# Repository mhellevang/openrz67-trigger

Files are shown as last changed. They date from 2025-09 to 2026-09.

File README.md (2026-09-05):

# openrz67-trigger

ESP32 firmware for remote-triggering the Mamiya RZ67 analog camera over Bluetooth LE. It runs on an ESP32-C3 connected to the camera's electrical remote port and is controlled from the companion Android app, [openrz67-android](https://github.com/openrz67/openrz67-android).

## Features

* Instant shutter release
* Bulb mode for remote long exposures
* Self-timer countdown with app-configurable duration
* Power-optimized: 80 MHz CPU with light sleep and 0 dBm BLE TX power, running off a small LiPo

## Hardware

The current prototype is a custom PCB (design and fabrication files in [`pcb/`](pcb/)):

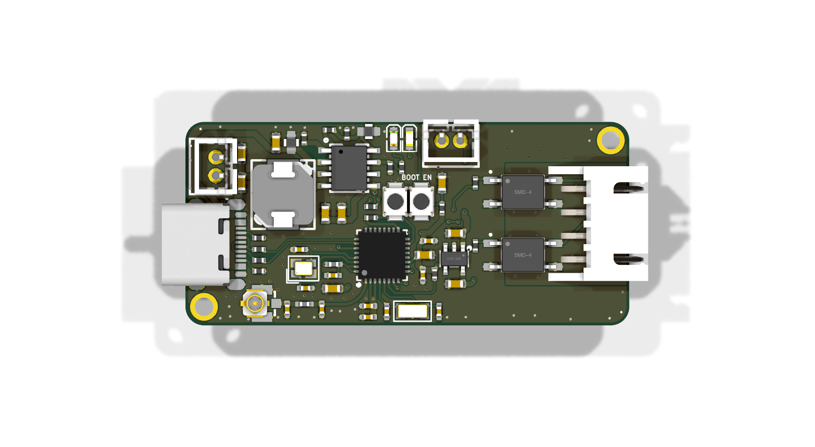
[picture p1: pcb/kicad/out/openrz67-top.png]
Custom PCB


The PCB source is the KiCad project in [`pcb/kicad/`](pcb/kicad/) (ported from EasyEDA Pro in September 2026). Generated Gerber/BOM/position files are in `pcb/kicad/out/`. The fabricated 2025-09-23 revision and the EasyEDA Pro exports are kept under [`pcb/archive/`](pcb/archive/).

The current source is **rev 2, not yet fabricated**: it swaps the G6K relays for PhotoMOS parts and changes `U4` to a side-entry connector; the battery connector stays on top. The board pictured above is rev 2, and the enclosure in [`case/`](case/) is drawn for it (not yet print-tested). Connector part numbers and geometry are documented in [`pcb/kicad/README.md`](pcb/kicad/README.md), which is the authoritative source for them.

* 1× ESP32-C3FH4
* 2× Toshiba TLP172AM PhotoMOS relays (solid-state, isolated) to close the shutter contacts
* Supporting components per the [BOM](pcb/kicad/out/openrz67-bom.csv)
* 2.4 GHz antenna with U.FL connector
* 250 mAh LiPo for power, on a JST B2B-PH-K-S top-entry connector (`BAT1`)
* SS12F15 slide switch

The solution is flexible: an ESP32-C3 development board such as the Seeed XIAO ESP32C3 and two isolated switch channels work too. Assign two output-capable GPIOs in `src/main.cpp`. On the PCB each channel is a TLP172AM PhotoMOS relay whose LED is driven from the GPIO through 220 Ω; the isolated output closes S1 or S2 to camera ground while the GPIO is HIGH. Keep ESP32 ground and camera ground separate.

Wiring diagram for the ESP32-C3, two TLP172AM PhotoMOS channels and the Mamiya RZ67 camera port

### Current PCB pinout

| GPIO | Function |
|---|---|
| 3 | Shutter output S2 (U6), net `S2_DRV` |
| 4 | Shutter output S1 (U5), net `S1_DRV` |
| 20 | Status LED |

### Camera connector

The custom PCB uses a JST S4B-XH-A four-pin header (`U4`), side-entry, opening out of the right board edge:

| U4 pin | Camera signal |
|---|---|
| 1 | Not connected (camera 6 V) |
| 2 | GND |
| 3 | S1 |
| 4 | S2 |

Verify the pin 1 orientation before assembling the camera cable.

## Camera connection

Viewed from the front, the camera's four-pin remote-control port is:

1. 6 V — do not connect
2. GND
3. S1 switch
4. S2 switch

To trigger the shutter release, the PhotoMOS outputs short S1/S2 to camera GND. For bulb exposures, set the camera's shutter-speed dial to `B`. The camera closes the shutter automatically after approximately 60 seconds even if the switches remain closed.

## BLE protocol

The device advertises as `OpenRZ67` with service UUID `c9239c9e-6fc9-4168-b3aa-53105eb990b0` and characteristic `458d4dc9-349f-401d-b092-a2b1c55f5319`. Send commands using Write Without Response.

**Single-byte commands** (value = button × 10 + state):

| Value | Action |
|---|---|
| 11 | Trigger shutter with a 100 ms pulse |
| 10 | Clear status LED; no shutter action |
| 21 | Start bulb mode |
| 20 | End bulb mode |
| 31 | Start countdown with the default duration of 10 s |
| 30 | Cancel countdown |

**Three-byte commands** `[command, duration, action]`:

| Bytes | Action |
|---|---|
| `[3, n, 1]` | Start countdown of *n* seconds (`1–255`) |
| `[3, _, 0]` | Cancel countdown |

Starting a trigger or bulb exposure cancels any pending countdown.

## Building

The project uses [PlatformIO](https://platformio.org/) and the `esp32-c3-devkitm-1` board definition:

```bash
pio run
pio run -t upload
```

If uploading does not start, hold `BOOT`, press and release `EN`, then release `BOOT` and retry.

Serial logging is disabled because UART0 RX is GPIO 20, which drives the status LED. Rev 1 also used GPIO 21 (UART0 TX) for a shutter output; rev 2 moved that output to GPIO 4, so TX-only logging is possible again.

## License

[MIT](LICENSE), covering the firmware in `src/`, the KiCad design files in `pcb/kicad/`
and the enclosure sources in `case/`. MIT is written for software, but its grant is broad
enough to serve a hardware design; if you need an instrument written for hardware, the
closest equivalent is CERN-OHL-P.

Two things in this repository are **not** covered, because they are not mine to license:

* The footprints in `pcb/kicad/openrz67.pretty/` and the symbols in `openrz67.kicad_sym`
  were imported from the EasyEDA/LCSC part libraries.
* The 3D models in `pcb/kicad/openrz67.3dshapes/` were fetched per LCSC part number with
  `easyeda2kicad`.

Both are redistributed here for convenience under their originators' terms. Everything
else is mine.

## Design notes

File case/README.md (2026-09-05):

# Parametric enclosure (build123d)

`openrz67_case.py` is a parametric two-part enclosure for the OpenRZ67 trigger PCB
**rev 2** (the KiCad project in `../pcb/kicad/`), written in
[build123d](https://build123d.readthedocs.io/) (Python). It is built from the board
file and its footprints, not from eyeballed measurements.

> Rev 2 keeps the 48 × 22 mm outline, the mounting holes, `BAT1` (top side, same
> place) and `S3` of the fabricated 2025-09-23 board, so the battery-beside layout
> carries over unchanged. What changed for the case: `U4` is now a **side-entry**
> S4B-XH-A whose body reaches **5.5 mm past the board edge**, so the cavity is 3 mm
> wider on the right and the connector passes through the lid wall; the G6K relays
> became low PhotoMOS parts. Not yet print-tested against a rev 2 board.

## Source data

Board coordinates in the script have the origin at the board's front-left corner
with Y toward the back; KiCad measures Y from the other long edge, so
`board_y = 22 - kicad_y` (`../pcb/kicad/out/openrz67-pos.csv` lists KiCad Y as
negative numbers — drop the sign).

| Measurement | Value | Source |
|-----|---|---|
| Board outline | 48.0 × 22.0 mm, R2.0 | `openrz67.kicad_pcb` Edge.Cuts |
| Mounting holes | 2× Ø2.0 at (2,2) and (46,20) | `MountingHole_2.0mm_Pad3.0` footprints |
| PCB thickness | 1.6 mm | `pcb_t` (as ordered) |
| Component placement | see openrz67_case.py | `out/openrz67-pos.csv` |
| U4 camera connector | side-entry S4B-XH-A, pin row at (44.3, 11), mouth facing +X; body 12.4 wide × 6.1 tall, 9.2 mm from pin row to mouth face and 2.3 to the rear face, i.e. the mouth sits 5.5 mm past the board edge | `CONN-TH_S4B-XH-A-LF-SN.kicad_mod` F.Fab + `.wrl` |
| USB-C connector | body 8.95 × 3.2 mm on the PCB, left edge 4.8 mm in from the PCB's left edge; the shell protrudes ~2 mm past the board edge | measured physically |
| Total HW length | ~50 mm (PCB 48 + USB-C shell 2) | `pcb_overhang_left` |
| Slide switch (SS12F15) | actuator opening 10.65×6.3; flat bracket 19.45×5.75×0.4; screw holes Ø2.2 at 15.0 mm spacing; body ~19.5×20×12.9 | `SS12F15.stp` + measured |
| LEDs | D3 red (22.5, 20.2), D4 blue (24.2, 20.2) – 0603 SMD, top-emitting, 1.7 mm apart | `out/openrz67-pos.csv` |

Component **heights** are editable constants (`h_usbc`, `h_ph_plug`, `xh_h`) from the
datasheets / 3D models. `h_ph_plug` (8 mm: a PHR-2 plug in the 6 mm PH header plus the
wire bend on top, on `BAT1` and `S3`) is the tallest thing on rev 2 and sets the lid
height. Check them against your own parts.

The script carries **module-level assertions**: outer dimensions, plus probe checks that
every opening actually breaks through (USB, LED window, locating-pin recesses, switch
screws) and that the fit-critical keepouts (switch body envelope, USB-C body, the U4
connector body through the right wall) stay open. They run on every export, so a parameter tweak that closes a hole or re-introduces
a known collision fails loudly instead of surfacing in the print.

## Construction
- **Base** (tub): floor, a **battery bay beside the PCB** (behind its back edge, separated
  by a divider wall), low standoffs that raise the PCB ~3.5 mm (only the through-hole
  solder tails need clearance underneath), **solid support pillars** in all four corners
  (`pcb_supports = [[2,20],[46,2]]` plus the two posts at the mounting holes), and two
  **Ø1.7 locating pins** up into the real Ø2 mounting holes.
  - **Through-hole solder relief** (`th_keepouts`): a small pocket in the top of a
    pillar where a through-hole component's pin tails/solder stick down (the pillar at
    (2,20) sits next to BAT1). The list is `[board_x, board_y, relief_diameter]`;
    `th_keepout_depth` sets how far down (default 3 mm).
  - **PCB frame / guide fins** (`frame_*`): the lap joint removes the inner wall at board
    height, so **guide fins** in the ~1.2 mm tongue channel hold the PCB sideways: a thick
    fin beside the board edge with `frame_clr` (0.2 mm) clearance, plus a thin lead-in
    lip `frame_proud` (0.6 mm) above the board top. The lid tongue is cut away where the
    fins sit (`frame_tongue_notch`, clearance `frame_notch_clr`). The board drops straight
    down and is captured in Y between the front fins and the battery-bay **divider wall**
    (whose front face sits `frame_clr` from the board's back edge — `frame_ribs_back = []`).
    `frame_ribs_front` are the fin centres in board-X (default `[10, 38]`).
- **Lid**: telescopes down into the base via a perimeter tongue-and-groove edge (lap
  joint) for alignment. Carries the USB-C opening (left), the opening for the U4
  camera connector (right), the LED light-pipe window (top), and the slot + screw
  pillars for the SS12F15 slide switch.
  - **U4 opening** (`cut_xh`): the side-entry S4B-XH-A body sits in a rectangular
    through-cut in the lid's right wall (body + `xh_clr` all round), open at the bottom
    so the lid simply drops over the connector; the XHP plug goes in from **outside**,
    like the USB-C. The mouth face ends `xh_recess` (0.3 mm) inside the outer wall face —
    `pcb_overhang_right` is derived from that, so a different connector reach
    (`xh_mouth`) moves the wall, not the connector. The old drop-in cable slit is gone:
    the cable no longer lives inside the box. The lid's (46,20) hold-down boss is cut
    back (`comp_keepouts`) where it would touch the connector body 0.3 mm away.
  - **LED light pipe** (`led_*`, separate part): D3 (red) and D4 (blue) are top-emitting
    SMD LEDs ~8 mm below the lid. A separate **clear light pipe** is inserted from above
    as a top hat: a wide head in a top counterbore (flush with the top face) + a rod that
    goes down to ~1.5 mm above the LEDs and channels the light into two sharp dots. The
    lid is printed opaque; **only the light pipe is printed in clear filament**. It rests
    in the counterbore (gravity + optionally a drop of glue to seal). Parameters:
    `led_win_l/w/r` (window size), `led_head_lip/t` (head/counterbore), `led_pipe_gap`
    (air gap to the LED), `led_pipe_clr` (fit in the hole). `led_pos` are the LED
    positions from pick&place.
  - **Component clearance** (`comp_keepouts`): rectangles `[board_x0, board_y0, board_x1,
    board_y1]` cut out of the lid's hold-down bosses (full height above the PCB) where a
    boss would collide with a component body — e.g. the Ø6 boss at hole (2,2) is cut back
    to a D-shape to clear the USB-C connector's near edge (~board-Y 4.8).
- **USB-C asymmetry**: the USB-C shell protrudes ~2 mm past the PCB's left short side.
  `pcb_overhang_left = 2.0` extends the cavity on the left; the PCB is therefore centred
  toward the RIGHT in the cavity (normal `clr = 0.4` against the right wall, `clr +
  overhang = 2.4 mm` against the left). On the right, `pcb_overhang_right` (3.0 mm,
  derived from the U4 reach) does the same for the camera connector. The outer case
  width thus becomes ~**58.6 mm**.
- **The battery** (250 mAh LiPo) lies **beside the PCB** in its own bay behind the board's
  back edge, bounded by the **divider wall** (front, top flush with the split — it doubles
  as the PCB's back guide), the case walls (back/sides), and two low ribs that stop the
  cell sliding in X. BAT1 sits at board ≈ (3.3, 17) on the PCB top, so the lead just
  **drapes over the divider** and plugs straight in — short and flat. Everything is
  assembled from above in one layer. The bay is taller than the cell; fix it with a foam
  pad or a dab of glue. Parameters: `batt_w/l/t` (cell), `batt_clr` (bay fit), `batt_dx`
  (X nudge), `divider_t`, `rib_h`.

## Closure — snap-fit
**No hardware at all.** A perimeter **bead** (`snap_bead` 0.5 mm, `bead_h` 1.4, chamfered
0.4 top and bottom — click-in/pry-out ramps, and the first printed bead layer isn't a ledge
in mid-air) on the lid tongue clicks into a matching **groove** in the base lip (0.5 taller
/ 0.25 deeper for lead-in, ceiling chamfered so it prints without an overhang), holding the
whole rim down — including the battery-bay half, which a corner-screw
pattern would leave unclamped. The PCB is located by two **Ø1.7 pins** in its real Ø2
mounting holes and pressed onto the posts by the lid's hold-down bosses (blind pin recesses
inside — no holes through the top). Open with a coin or fingernail in the **pry slot**
(`pry_w/d/h`) on the back wall's lower lid edge, over the battery bay.

The case is rarely opened (charging is external via USB-C), so snap wear is not a concern
with PLA; print the lid in PETG if you want extra flex margin. **Tune before the full
print:** `SNAP_TEST=true ./export.sh` also exports a cropped front-left corner pair
(`openrz67-snaptest-*`) — print those and adjust `snap_bead` (click strength) and
`lap_gap` (sliding fit) until the corner snaps shut and pries open with reasonable force.

Finished size with default values: ~**58.6 × 50.0 × 18.1 mm** (X incl. the 2 mm USB-C
overhang and the 3 mm U4 overhang, Y incl. the battery bay behind the board, Z depends
on `pcb_t`).

## Orientation mark — `orient_mark`
A small **raised rib** on the front wall (low Y) near the left corner, split across the
seam: the base carries the lower half, the lid the upper half. When the lid is on the
right way around the two halves line up into **one continuous vertical rib**; a lid put on
180° wrong moves its half to the opposite corner, so the mismatch is obvious at a glance.
It is raised (not a recessed groove) on purpose — a groove here would thin the 1.2 mm lap
wall. Parameters: `orient_mark_x` (board-X of the mark, near the USB side), `orient_mark_w`
(width), `orient_mark_d` (how far it sticks out), `orient_mark_h` (total height across the
seam). Delete the two `orient_mark_rib` lines to remove it.

## Lid text — second colour (`lid_texts`)
**Debossed badge layout** around the LED window: **"OpenRZ67"** (9 mm caps) above it,
**"Trigger"** (7 mm) below, both centred on the light pipe's X, cut `lid_text_depth`
(0.6 mm) into the top face. Per the FDM rules: pockets, not raised letters, and well above
the 4.4 mm legibility minimum for a 0.4 nozzle. Placement is enforced by assertions (each
line must clear the LED recess, the walls and the face edges — an over-long string fails
the export instead of the print).

Colour it in the slicer with a **height range modifier on the lid**: select the lid,
add a height range **0.6–1.4 mm** and assign it the letter-colour filament. The lid prints
**upside down** (the pockets face the bed and come out crisp), so those four layers form
the pocket floors — the letters show in the contrast colour, recessed in the face colour,
with only a thin accent band at the lid's top edge. On a single-filament printer, do a
manual filament change at Z = 0.6 instead (recolours everything above 0.6, so slice the
lid alone).

**Do not save the height range into the project/template**: QIDI Studio (≤ v2.x)
**segfaults on opening** a .3mf that carries `Metadata/layer_config_ranges.xml`
(`ObjectList::add_settings_item` dereferences the not-yet-created model tab during
startup load). Add the range fresh after opening the project instead.

Edit the `lid_texts` constant to change strings/sizes/offsets; `LID_TEXT_SHOW=false`
disables the text (on by default).

## Usage
The parameters are plain Python constants at the top of `openrz67_case.py`. Requires
[uv](https://docs.astral.sh/uv/) — the script carries its own dependency header, so there
is no venv to manage.

**Easiest export** – run the script, which builds all three parts and the slicer project:

```bash
cd case
./export.sh            # base, lid, lightpipe -> stl/  + openrz67-case.3mf
./export.sh out        # custom output dir (skips the .3mf)
```

**Overrides** – `openrz67_case.py` reads these from the environment (the in-file default
applies when unset); anything else is a one-line edit of the constant:

```bash
LID_TEXT_SHOW=true   ./export.sh   # turn the lid text ON (off by default; for the final print)
LID_TEXT="My text"   ./export.sh   # change the lid text string
LID_TEXT_SIZE=4.0    ./export.sh   # cap height (mm)
SNAP_TEST=true       ./export.sh   # also export the corner test pair for snap tuning
PCB_T=1.0            ./export.sh   # PCB thickness (sets the base/lid split height)
LID_TEXT_SHOW=true LID_TEXT="v2" ./export.sh     # combine freely
```

Or run the script directly (same thing minus the .3mf step): `uv run openrz67_case.py`.
For a plain interpreter (IDE run button etc.) there is a local venv:
`.venv/bin/python openrz67_case.py` — recreate it anytime with
`uv venv .venv && uv pip install -p .venv "build123d>=0.11.1"` (it is git-ignored).
For an interactive 3D preview, open the file with an OCP viewer (e.g. `ocp_vscode`) or
just inspect the exported STLs in the slicer. STL output in `case/stl/` is git-ignored.

### Slicer project (.3mf)

After the STLs, `export.sh` rebuilds `openrz67-case.3mf` — a
**Bambu Studio / OrcaSlicer project** with the three parts arranged on the plate, the print
profile, and the **per-part filament assignment** (base + lid on filament 1, light pipe on
filament 4 = clear). It does this by swapping the fresh meshes into a hand-made template
(`bambu-template.3mf`) via `make_3mf.py`, so all slicer settings are preserved — only the
geometry changes. Skip it with `MAKE_3MF=false ./export.sh`, or run it standalone:

```bash
python3 make_3mf.py            # template + stl/ -> openrz67-case.3mf
```

To change the print settings, plate layout, or filament mapping, edit the project once in the
slicer and re-save it over `bambu-template.3mf`; subsequent exports inherit the new setup.
The plate thumbnails inside the .3mf are not regenerated (they show the template's geometry);
the slicer refreshes them when you open or slice the project — purely cosmetic.

## Print orientation
- **Base**: print as-is (floor down). No supports needed.
- **Lid**: print **upside down** (top plate against the bed). That way the bosses/lip
  point upward with no overhang and the LED window/counterbore gets a clean top surface.
- **Light pipe** (`openrz67-lightpipe.stl`): **clear filament**. Print upright (head down
  against the bed) for the fewest layer lines across the light path, or lying down for
  smoother walls – both work for an indicator. For the clearest light: print at a fine
  layer height and consider sanding/dipping the top face.

## Worth adjusting before printing
- `pcb_t` – PCB thickness (default **1.6 mm**, as ordered). Adjust only if your board
  differs; it sets the height of the base/lid split.
- `pcb_overhang_left` – the air gap on the left for the USB-C shell. Measure your own
  connector: distance from the PCB's left edge to the outermost point of the shell.
  Default 2.0.
- `pcb_supports` – extra support-pillar coordinates (without screw) on the base. Default
  is the two empty corners `[[2,20],[46,2]]`; add more if the board flexes.
- `h_ph_plug` – the tallest component (PHR-2 plug + wire bend on `BAT1`/`S3`) sets the
  total height. Lower it if your plugs sit lower.
- `xh_mouth` / `xh_recess` – how far the U4 body reaches past its pin row, and how far
  inside the outer wall face its mouth ends. Together they set `pcb_overhang_right`.
- `snap_bead` / `lap_gap` – snap click strength and sliding fit. Tune with the
  `SNAP_TEST=true` corner pieces before printing the whole box.
- `batt_w/l/t` / `batt_clr` – fit your LiPo in the bay; `batt_dx` nudges it in X if the
  leads want a different exit point.
- `sw_x` / `sw_z` / `sw_wall` – position of the slide switch. The **front wall**
  (`"front"`, low Y) is chosen deliberately: the back wall carries the S3 connector
  (board-X 28.7), the LEDs and the battery-bay divider, so there's no room there for a
  centred switch with 15 mm boss spacing. `sw_x = 22` is practically centred (case centre
  is 23; the bosses at board-X 14.5 and 29.5 sit over low 0402/0603 parts only).
  The wire from S3 runs across the board to the switch. Verify against your own components.
- **Switch screw mount**: the switch's flat bracket mounts on the **outside** of the case;
  screws go from outside → through the bracket and wall → thread into two **rectangular
  pillars** that hang from the lid ceiling down to `sw_boss_gap` (1.5 mm) above the PCB. The
  pillars are anchored in the top plate and their front sits at the inner wall plane against
  the (now solid) inner wall, so tightening clamps **bracket → wall → boss** in compression —
  no free-standing cantilever. The `sw_boss_gap` air gap keeps the pillars clear of the
  densely packed front components under their footprint (Q1 SOT-23 ~1.1 mm, C15/C26 0603
  ~0.9 mm). `sw_screw_pitch` = 15.0 (centre spacing, ±7.5), `sw_screw_d` = 2.4
  (M2 clearance), `sw_boss_d/h/pilot` set the pillar cross-section and pilot hole.
  - **Body keepout** (`sw_body_l × sw_body_h × sw_body_w` = **11 × 7 × 8 mm**, + `sw_body_clr`
    0.4/side): the switch body that protrudes inside is wider than the gap between the
    bosses, so a keepout carves the body envelope out of the cavity, relieving the boss
    inner faces over the body's Y/Z extent only — the screw region (±7.5) and the pillar
    above the body stay full. Verify `sw_body_l/h/w` against your switch.
  - **Actuator opening** (`sw_slot_l × sw_slot_h`): **10.65 × 6.3 mm** through the wall,
    centred on `sw_x`/`sw_z`.
  - **Screw**: **M2 self-tapping**, ~**8 mm** long (M2×6 also fine). From outside through the
    bracket (0.4) + wall (1.6 behind the recess), threading `sw_boss_pilot` (1.5) into the
    pillar (up to `sw_boss_h` 5 mm engagement). The head sits on the external bracket, so the
    case has no head counterbore.
  - **Bracket recess** (`sw_plate_recess`, default on): the flat bracket (`sw_plate_w ×
    sw_plate_h × sw_plate_t` = **19.45 × 5.75 × 0.4 mm**) mounts on the **outside**, sitting
    in a pocket `sw_plate_t` deep cut into the **outer** wall so it is **flush** with the
    outside. The inner wall behind it stays solid, which is what the bosses bear against.
    `sw_plate_clr` (0.3) adds fit clearance around the bracket. Verify `sw_plate_w/h/t`
    against your switch; set `sw_plate_recess = false` to drop the pocket.

## USB-C opening
Two layers in the wall (outside in):
- `usb_open_w/h` = **11 × 7 mm**, R2 (`usb_open_r`) – pass-through through the whole wall.
  This outer edge IS the **lip** that stops the cable body/overmold (anything > 11 × 7)
  from coming in; the metal plug itself (~8.34 × 2.56) passes through easily.
- `usb_recess` (**on**) – an **inner recess** `usb_recess_w/h/d` = **13 × 9 × 1.5 mm**,
  R3 (`usb_recess_r`), on the cavity side of the wall. It eats away the last 1.5 mm of
  the wall so the USB-C receptacle's body/shell can poke slightly into the wall and bring
  the connector mouth close to the outer face.

The opening's centre sits ~1.65 mm **above** the base/lid split, so the lower ~1.85 mm of
the 7 mm-tall window falls below the seam. `cut_usb()` therefore runs in **both** `base()`
and `lid()` — otherwise the base side wall would block the lower edge of the hole.

Measure your own charging cable and adjust if needed. Test with a print of just the left
short end first.

## Known / to verify
- Check that your charging cable reaches the port (see "USB-C opening" above).
- Check that the wire bundle from the XH cable fits the `cable_port_*` mouth.
- **Light pipe**: verify the rod lands directly over D3/D4 (adjust `led_pos` if needed)
  and that the bottom clears the LEDs (`led_pipe_gap`). Print in clear filament; glue the
  head into the counterbore for a permanent/sealed fit.
- The USB-C and switch openings are open out of necessity; the LED window is sealed by
  the light pipe.

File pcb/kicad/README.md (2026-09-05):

# openrz67 PCB — KiCad project

KiCad 10 project for the OpenRZ67 trigger board (48 × 22 mm, 2 layers, ESP32-C3,
two TLP172AM PhotoMOS relays, LGS5500 charger/boost). This is now the **source**; the EasyEDA Pro
project it was ported from is archived in `../archive/easyeda/` (v2 `.epro` and v3 `.epro2`);
the fabricated 2025-09-23 revision (Gerber, BOM, PnP, STEP) is in `../archive/2025-09-23-rev1/`.

| File | What |
|---|---|
| `openrz67.kicad_pro/.kicad_sch/.kicad_pcb` | project, schematic (1 sheet), board |
| `openrz67.kicad_sym`, `openrz67.pretty/` | symbols and footprints as imported from EasyEDA/LCSC (project-local libs) |
| `tools/regen.sh` | rebuilds everything in `out/` in one go; run it after any change to the board or schematic |
| `tools/post_import.py` | design rules, net classes, zone settings, layer names. **Authoritative**: it overwrites `openrz67.kicad_pro`, so rule changes made in Board Setup are reverted on the next run. Edit the values in the script. Rewrites the board in place, so close KiCad first. Idempotent. |
| `tools/fetch_3d.sh` | downloads STEP+WRL models for every LCSC part into `openrz67.3dshapes/` (uses `easyeda2kicad`, `uvx`, `pipx` or a local venv, whichever exists) |
| `tools/export_step.sh` | board STEP to `out/openrz67.step` (gitignored, ~20 MB); fetches missing part STEPs first |
| `openrz67.3dshapes/` | 3D models; `.wrl` committed (render), `.step` gitignored (fetch when you need a board STEP) |
| `out/` | generated: Gerber+drill zip, position file, BOM (with LCSC numbers), schematic PDF, top/bottom renders, ERC/DRC reports |

## Regenerate outputs

Everything in `out/` is generated. Rebuild all of it with one command, so the
committed outputs and the check reports always describe the committed sources:

```sh
tools/regen.sh
```

It runs `post_import.py`, exports Gerbers, drill files and their maps, zips them,
writes the position file, the BOM, the schematic PDF and the two board renders,
then runs DRC with schematic parity and ERC. It exits non-zero on errors;
warnings are printed and accepted (see below). Close KiCad first: `post_import.py`
rewrites the board and the project file in place.

Override the tool paths if KiCad is not in the macOS default location:

```sh
KICAD_CLI=/usr/bin/kicad-cli KICAD_PY=/usr/bin/python3 tools/regen.sh
```

## Design rules (from the EasyEDA project)

Clearance 0.127 mm (EasyEDA pour-to-track minimum; track-to-track was 0.152), min track
0.127, default track 0.16, via 0.45/0.20 (min 0.40/0.20), hole-to-track 0.175,
hole-to-hole 0.30, solder-mask expansion 0.051, thermal spoke 0.254 / gap 0.152.
Net classes: `gnd` (GND, 0.13 track), `3v` (VCC, 0.20), `5v` (+5V, 0.254 track, 0.5/0.3 via).
Copper-to-edge clearance is 0.30 mm (JLCPCB recommendation; the original pours ran to
the outline). Silkscreen minimums are JLCPCB's: 1.0 mm text height, 0.15 mm line width.

## Accepted warnings

ERC is clean: **0 errors, 0 warnings**. DRC has no errors; the warnings below are known,
understood and left in the reports rather than silenced, so a genuinely new one stands
out. No DRC or ERC exclusions are configured.

| Check | Count | What |
|---|---|---|
| `courtyards_overlap` | 5 | Neighbours closer than 0.1 mm on the fabricated rev-1 layout: C21/USB1, L3 against C20/R9/R12, H1/USB1. |
| `text_height`, `text_thickness` | 2 | The `BOOT EN` label on F.SilkS is 0.5 mm / 0.10 mm, under JLCPCB's 1.0 mm / 0.15 mm. Enlarged in place it runs over the R18 pads and the S3 body, where the fab clips silkscreen against solder mask. Splitting it into separate `BOOT` and `EN` labels does not help: the free band above the S1 pads is 0.85 mm and the one below the switches is 0.7 mm, both under the 1.0 mm the text needs. Fixing it means moving parts. Every other silkscreen text is at or above 1.067 mm. |

## Rev 2 layout changes (2026-09-03)

Outline unchanged from rev 1: **48 × 22 mm**, 2 mm corner radius, mounting holes at
(2, 20) and (46, 2). Edges are named here by their landmark, because the enclosure in
`../../case/` measures Y from the opposite side: the **USB-C end** is x = 0, the
**camera end** is x = 48, the **S3 edge** is y = 0, and the **switch edge** is y = 22.

- **U4** camera connector: side-entry S4B-XH-A (LCSC C157925) at (44.3, 11.0), opening
  out of the camera end.
- **BAT1** battery connector: vertical through-hole **B2B-PH-K-S(LF)(SN)** (LCSC C131337)
  on the **top** side, restored on 2026-09-05 from the layout before `d7d51ae`.
  Centre (3.275, 4.8105), rotation 90°. Pin 1 = BAT+, pin 2 = GND.
  The original 0.635 mm top-side BAT+ connection and five GND stitching vias are restored;
  the bottom-side BAT+ branch and its transfer via are removed. `BAT+` / `BAT-` labels
  on the bottom identify the through-hole solder pads. All components are now on top.
  The battery cable must reach around the board if the cell remains underneath.
- **Shutter outputs are PhotoMOS, not relays (2026-09-04).** K1/K2 (G6K-2F-Y), their DTC114E
  drivers Q1/Q2, flyback diodes D1/D2 and coil decoupling C27/C28 are gone. Each channel is one
  **TLP172AM** (Toshiba, LCSC C2152276, 4-pin SO6): the ESP32 GPIO drives the LED through a
  **220 Ω** 0402 (R21/R22, C25091), about 9 mA nominal. At 3.3 V, VOH = 0.8 × VDD,
  VF = 1.4 V and +1% resistance give 5.6 mA at 25 °C, within the datasheet's 5 to 25 mA
  recommendation. The MOSFET output closes S1/S2 to camera ground.
  TLP172AM replaced TLP172GM on 2026-09-05: maximum on-resistance is 2 Ω at 25 °C / IF = 5 mA,
  versus 50 Ω continuous for GM. AM's output rating is 60 V / 500 mA; package and pin functions
  are unchanged. The imported pad numbering 1/2/3/4 maps to Toshiba pins 1/3/4/6.
  Firmware activates S1, waits 10 ms, then activates S2. Camera input limits remain unverified;
  test the assembled prototype before ordering a production batch. See [research notes](notes/rz67-remote-inputs.md)
  and the [Toshiba datasheet](https://toshiba.semicon-storage.com/info/docget.jsp?did=36714&prodName=TLP172AM).
  U5 = S1 (net `S1_DRV`, **GPIO4**, U1 pin 9), U6 = S2 (net `S2_DRV`, GPIO3, U1 pin 8). Rev 1
  drove S1 from GPIO21, which is U0TXD: the ROM boot log leaves it high until `setup()` runs,
  so S1 was closed during every boot. Harmless alone, since the camera needs S1 and S2 together,
  but GPIO4 is a plain input at reset and GPIO21 is now free for serial logging. Isolation is kept: camera ground `AGND` still touches only U4 pin 2 and the two
  output pins, and the AGND pours (both layers) were pulled in from x = 32.1 to x = 34.6 so the
  LED side of each part sits in the GND domain. Eight parts became four, the tallest top-side part
  went from 5.2 mm (relay) to 2.2 mm, and the coil current (about 67 mA while an exposure is
  held) is gone. Footprint `SMD-4_L4.6-W3.7-P2.54-LS7.0-BR` and the 3D model came from
  `easyeda2kicad` for C261926; the unused relay/SOT-346/SOD-523 footprints, models and symbols
  were removed from the project libraries. R4/R5 (USB 22 Ω) are UNI-ROYAL 0402WGF220JTCE
  (C25092, JLCPCB Basic) since JLCPCB had 2 of the Yageo part in stock.
- **C5** moved to the analog supply: the 100 nF that sat on VCC next to the ferrite bead
  L2 now sits on the far side of it, on the new **VDDA** net feeding U1 pins 31/32 (radio and
  ADC supply). Before, nothing decoupled that net; the bead alone was just series impedance.
  VCC reaches L2 pin 1 through a new via beside the pad. Same part, same position, no BOM
  change. B.Cu ground under U1 stays one region (648.7 mm²).
- **Under-board clearance** the enclosure has to provide, from the datasheets:

  | What | Height below the board |
  |---|---|
  | BAT1 through-hole tails, B2B-PH-K-S | 3.4 mm unclipped |
  | S3 through-hole tails, B2B-PH-K-S | 3.4 mm unclipped |
  | U4 through-hole tails, S4B-XH-A | 3.4 mm unclipped |
  | USB1 shell posts | ~1 mm |

  The cell can only sit against the board if those tails are **clipped flush**. Budget
  3.4 mm otherwise. A foam pad between cell and board is still wanted, but 1.5 mm of it
  only fits after clipping.

**Removed again:** an earlier attempt widened the board to 25 mm for an unpopulated 1×3
expansion header (GPIO4 / 3V3 / GND) along the switch edge. It was reverted. Reaching the
new edge strip forced the GPIO4 return path across the bottom pour, which split the B.Cu
ground under U1 and LDO1 into two islands and displaced three stitching vias next to the
antenna trace. One GPIO, on a header that was not going to be populated, did not pay for
that. There is no room on this outline for a through-hole header: a hole needs both layers
clear at once, and only two isolated spots on the whole board qualify. Bottom-side solder
pads do fit, but the cell now occupies the bottom. Revisit it together with the enclosure.

## Ordering

`out/gerber/` is tracked unpacked, so a revision's copper is diffable in git.
`tools/regen.sh` also writes `out/openrz67-gerber.zip`, which is what you upload;
it is gitignored because it is one command away and would otherwise churn the
history as a binary blob on every regen. When a revision is actually ordered, copy
the zip, BOM and position file into `../archive/<date>-rev<n>/` as the record of
what was fabricated.

JLCPCB's uploader asks you to map columns; the exports do not use its header names:

| JLCPCB field | Column in `out/openrz67-bom.csv` |
|---|---|
| Comment | `Value` |
| Designator | `Designator` |
| Footprint | `Footprint` |
| LCSC Part # | `LCSC` |

The position file is rewritten by `regen.sh` into JLCPCB's CPL layout (`Designator, Mid X,
Mid Y, Layer, Rotation`, mm suffix); their parser rejects KiCad's native header with
"Failed processing the CPL file". Origin is the drill-file origin at the board's top-left
corner, the same convention JLCPCB accepted for rev 1, and rotations for the top-side
parts are unchanged since that order. BAT1 is back on top with its original through-hole
footprint and rotation. Check BAT1 pin 1 in the fab's assembly preview before confirming.
No bottom-side component assembly is needed. BAT1, S3 and U4 are through-hole parts;
confirm the assembler's through-hole service or hand-solder them after SMD assembly.

## Port notes (2026-09-03)

- Import path: EasyEDA Pro **v2** `.epro` → KiCad "Import Non-KiCad Project". The v3
  `.epro2` export loads as an empty board in KiCad 10.0.6.
- Removed the "JeefunPCB" A3 sheet-frame symbol that came with the EasyEDA template
  and replaced it with a KiCad title block. Annotated the 62 power flags (`#PWR001…`),
  deleted two floating GND flags, added a no-connect on U4 pin 1.
- EasyEDA local labels became global labels so net names match the board (`BAT+`, `D7`, and the
  Wemos-style `D1`/`D6`, renamed `S2_DRV`/`S1_DRV` on 2026-09-04); EasyEDA auto-nets (`$1N…`) were renamed to KiCad's `Net-(…)` names.
  Connectivity was verified pad-for-pad against the schematic netlist before renaming.
- USB-C shell pads 13/14 are GND in the schematic; the EasyEDA board had them net-less.
  They are GND now (they sit in the GND pour).
- Schematic footprint fields for L2 (L0603→L0402), U1 (TL→BL QFN variant) and
  R18 (R0603→R0402) were corrected to what is actually on the board.
- DRC: 0 errors, 0 unconnected, schematic parity clean. Remaining warnings are silk
  overlaps/courtyards from the LCSC footprints. Two dangling vias (+5V_VIN, a duplicated
  VCC via) and a 0.1 mm track stub from the original layout were removed. Two small USB1
  polygons that the importer put on Edge.Cuts (not in the EasyEDA outline) moved to F.Fab.
- Gerber check against the fabricated 2025-09-23 set: copper and mask match apart from
  U4 (now S4B-XH-A side-entry instead of B4B-XH-A) and pour-fill details after KiCad's
  refill (thermal shapes); silkscreen differs in font rendering only.
- 3D models: the importer left dangling `EASYEDA_MODELS/…` references. Models were fetched
  per LCSC number with `easyeda2kicad` (`tools/fetch_3d.sh`) and both the board footprints and
  the library `.kicad_mod` files repointed to `openrz67.3dshapes/<name>.wrl`, keeping the
  importer's offsets/rotations, so "Update Footprints from Library" does not undo it. Board STEP:
  `kicad-cli pcb export step --subst-models -o out/openrz67.step openrz67.kicad_pcb`
  (needs the `.step` files, run `tools/fetch_3d.sh` first).
- Bottom silkscreen label changed from "EPS32-C3 Camera Trigger V1.0 / 2025-08-23" to
  "OpenRZ67 Trigger v2 / 2026-09".
- Pin electrical types were set by hand for the ICs (ESP32-C3, LGS5500, ME6211, USB-C);
  passives, connectors and the PhotoMOS pins are `passive`. Supply nets without a driver carry `PWR_FLAG`
  (GND, AGND, BAT+, VBUS, +5V_VIN, VDDA). ERC runs at default severities: 0 errors, 0
  warnings. The eight dangling wire ends inherited from the EasyEDA drawing were removed
  (an orphan S1/S2/AGND label cluster and three over-long wire tails); the netlist is
  unchanged, verified node-for-node before and after.
- The two mounting holes are real footprints (`MountingHole_2.0mm_Pad3.0`, plated 3.0 mm pad,
  2.0 mm drill) with `MountingHole` symbols H1/H2 in the schematic (excluded from BOM/POS).
- Courtyards were regenerated as pad/body bounding boxes (+0.05 mm) — the LCSC ones were
  oversized. Silkscreen outlines of 0402/0603 parts and of the two overhanging connectors
  (USB-C, U4) live on F.Fab now. DRC: 0 errors, 6 courtyard warnings where neighbours are
  closer than 0.1 mm on the fabricated layout (C28/S3, C21/USB1, L3 vs C20/R9/R12, H1/USB1).
- The library symbol file was pruned to the symbols in use; the schematic's embedded copies are
  regenerated from it, so "symbol differs from library" warnings are gone.

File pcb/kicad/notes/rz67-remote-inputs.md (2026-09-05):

# RZ67: S1/S2 and contact resistance

Investigated on 2026-09-05. Documentation only, not production approval. No components changed.

## Conclusion

The manual describes the functions, contact labels, and camera battery current, but no specification was found for S1/S2 input current, threshold voltage, or maximum contact resistance. The online research likewise found no verified measurements of these values. This does not mean the information has never been published.

Low contact resistance is a reasonable way to reduce uncertainty. The TLP172AM is a better candidate than the TLP172GM in terms of voltage drop, but this alone does not establish camera compatibility. A final selection also requires checks of current, voltage and transients, temperature, leakage, timing, and LED drive.

## What the original manual actually says

Source: [Mamiya RZ67 repair manual](/Users/mathiashellevang/Koofr/Manualer/Mamiya-RZ67-repair.pdf). Page numbers below refer to the printed page numbers. The entire document was searched using OCR, and the relevant pages were also inspected visually. OCR may miss text.

| Page | Information | Relevance to the trigger |
|---|---|---|
| 95, fig. 114 | VS at viewfinder contact 2: 3.2 V ±2 mV. Appears when S1 is activated with an RZ lens; adjusted with VR1. | Reference output to the viewfinder, not the S1/S2 threshold or permitted voltage drop across the switch. |
| 102 | The winder's 9 V is converted to approximately 6 V, including for the RC connector. | Do not assume that BW on the RC connector is the camera's regular battery output. |
| 104, fig. 122 | RC connector: 6 V/BW, Ground, S1, S2. | Identifies the signals without specifying electrical input limits. The order in the drawing is not a universal pin numbering when viewed from the front of the plug. |
| 106 | S1 activates at approximately 0.5 mm of button travel; S2 at approximately 2 mm. | Supports activating S1 before S2, but does not specify a minimum interval in milliseconds. |
| 114, C-2 / fig. 131 | 3–7 mA with S1 on; 16–21 mA during release with a shutter speed of 1 or 4 seconds. | Measured in the battery supply using a dummy battery. Not measured through the RC contacts and not a specified limit for short current spikes. |
| 116, fig. 132-A | Disconnected moving-coil unit: approximately 6 Ω. | Applies to the actuator, not the resistance of the RC input. It cannot be used to calculate contact current without the intermediate circuit. |

## Indirect evidence from original accessories

[Mamiya Electromagnetic Cable Release](https://ianbfoto.com/downloads/Mamiya%20645/Mamiya%20Electromagnetic%20Cable%20Release.pdf), one page, visually inspected: Type B has approximately 4 m of straight cable. The button has a half-press for metering and a full press for release. Wire gauge, contact resistance, and input limits are not specified. Wires and connectors have finite resistance, so the camera does not require an ideal 0 Ω switch. This still does not establish a numerical resistance limit.

[Mamiya RS401](https://ianbfoto.com/downloads/Mamiya%20645/Mamiya%20645%20RZ67%20Remote%20Control%20RS401.pdf), four pages, visually inspected: describes the original wireless remote release for the RZ67 series and other cameras. No S1/S2 current, contact resistance, or threshold voltage was found in this manual.

[Jan Griffioen's repair](https://jantecnl.synology.me/en/mamiya-rz67-repair-shutter-release-electronics-problem/) states that he had the service manual but had to work from block and wiring diagrams without a functional electronic schematic. This describes the sources available to him, not proof that such a schematic does not exist.

## Component comparison

- [Omron G6K](https://components.omron.com/us-en/system/files/2026-05/datasheet_pdf/K106-E1.pdf): maximum initial contact resistance of 100 mΩ (0.1 Ω), measured at 10 mA / 1 V. The coil resistance is not the resistance seen by the camera.
- [Toshiba TLP172GM](https://toshiba.semicon-storage.com/info/TLP172GM_datasheet_en_20230525.pdf?did=36716&prodName=TLP172GM): maximum R_on of 35 Ω for a short measurement under 1 s and 50 Ω continuously, under the datasheet test conditions at 25 °C and 5 mA LED current.
- [Toshiba TLP172AM](https://toshiba.semicon-storage.com/info/docget.jsp?did=36714&prodName=TLP172AM): maximum R_on of 2 Ω under the datasheet test conditions at 25 °C and 5 mA LED current. The output is rated for 60 V / 500 mA; the limits must be assessed with derating. This is not a guarantee of camera compatibility.

Illustrative calculation, not measured contact current: If 7 mA flowed through the switch, 50 Ω would produce a 350 mV voltage drop and 2 Ω would produce 14 mV. At 21 mA, the values would be 1.05 V and 42 mV. It has not been established that the camera's battery current flows through S1 or S2. These figures are therefore not a worst-case calculation for the camera.

## Scoped next test

An external adapter connected at the already verified RC pinout can be used to compare the working mechanical relay with known series resistances in each signal wire, both individually and together. Do not use the BW pin or apply an external voltage. Check half-press, release, bulb mode, and operation with a weaker battery. This tests the contact resistance tolerance of the specific camera, but does not replace checks of PhotoMOS leakage, current spikes, switching time, or testing with other camera models.

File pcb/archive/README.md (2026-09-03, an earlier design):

# PCB archive

Historical PCB material. Nothing here is the source of truth: the live design is
the KiCad project in [`../kicad/`](../kicad/).

## `2025-09-23-rev1/`

The fabrication package for **rev 1**, the revision that was actually manufactured
and assembled, exported from EasyEDA Pro on 2025-09-23. This is what the enclosure
in [`../../case/`](../../case/) is built against.

| File | What |
|---|---|
| `Gerber_…zip` | Gerber and drill files as ordered, including the board outline (`.GKO`) and `Drill_PTH_Through.DRL` |
| `BOM_…csv` | bill of materials as ordered |
| `PickAndPlace_…csv` | component placement as ordered; the source for the case's component positions |
| `3D_…step` | assembled board as STEP |
| `3D_…png` | render |

## `easyeda/`

The EasyEDA Pro project the KiCad port was made from, kept so the port stays
reversible.

| File | What |
|---|---|
| `ProPrj_…epro` | EasyEDA Pro **v2** export. This is the one that imports into KiCad; use it if the port ever has to be redone. |
| `ProPrj_…epro2` | EasyEDA Pro **v3** export. KiCad 10.0.6 imports this as an empty board, so it is kept for EasyEDA's own use only. |

The filenames carry spaces because they are the exports as EasyEDA produced them.
They are left unrenamed so they can be matched against the cloud project.

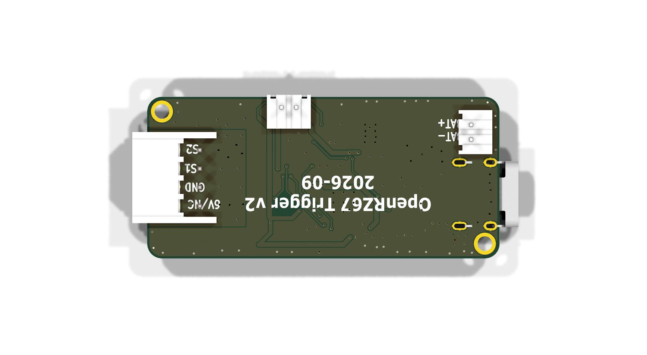
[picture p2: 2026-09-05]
pcb/kicad/out/openrz67-bottom.png

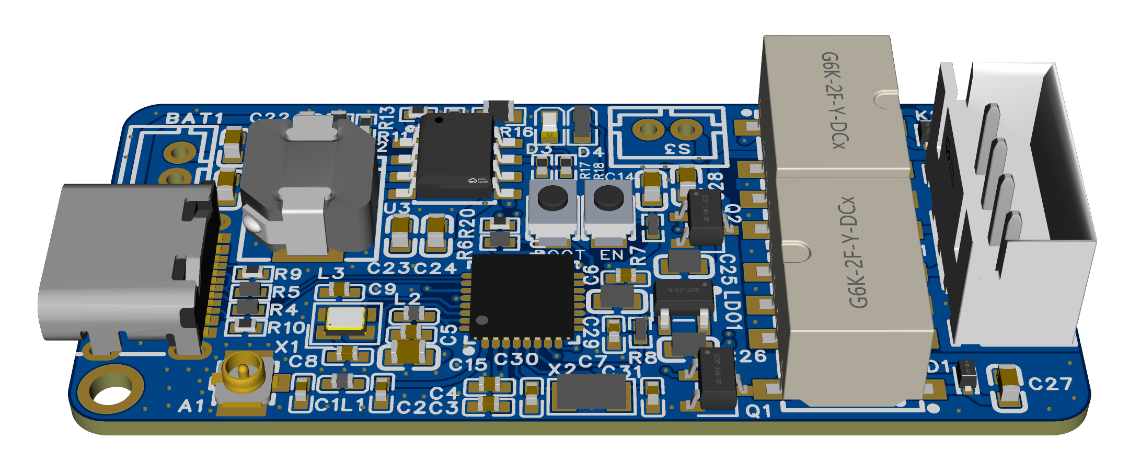
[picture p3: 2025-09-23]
pcb/3D_ESP32CamTrigger_PCB_2_2025-09-23.png

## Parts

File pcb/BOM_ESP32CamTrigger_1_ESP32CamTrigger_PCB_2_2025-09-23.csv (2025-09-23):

No. | Quantity | Comment | Designator | Footprint | Value | Manufacturer Part | Manufacturer | Supplier Part | Supplier
1 | 1 | U.FL-R-SMT-1(80) | A1 | RF-SMD_FRF05002-JSS103M |  | U.FL-R-SMT-1(80) | HRS(广濑) | C88374 | LCSC
2 | 2 | B2B-PH-K-S(LF)(SN) | BAT1,S3 | CONN-TH_B2B-PH-K-S |  | B2B-PH-K-S(LF)(SN) | JST | C131337 | LCSC
3 | 2 | 1pF | C1,C2 | C0402 | 1pF | CC0402CRNPO9BN1R0 | YAGEO(国巨) | C277493 | LCSC
4 | 5 | 100nF | C3,C4,C5,C6,C7 | C0402 | 100nF | GRM155R71H104KE14D | muRata(村田) | C77020 | LCSC
5 | 2 | 15pF | C8,C9 | C0402 | 15pF | GJM1555C1H150FB01D | muRata(村田) | C441742 | LCSC
6 | 4 | 1uF | C14,C25,C26,C29 | C0603 | 1uF | CGA0603X5R105K500JT | HRE(芯声) | C6119852 | LCSC
7 | 8 | 10uF | C15,C20,C21,C22,C23,C24,C27,C28 | C0603 | 10uF | CL10A106MA8NRNC | SAMSUNG(三星) | C96446 | LCSC
8 | 2 | 18pF | C30,C31 | C0402 | 18pF | GRM1555C1H180FA01D | muRata(村田) | C161534 | LCSC
9 | 2 | 1N4148WT | D1,D2 | SOD-523_L1.2-W0.8-LS1.6-RD |  | 1N4148WT | onsemi(安森美) | C232841 | LCSC
10 | 1 | KT-0603R | D3 | LED0603-RD |  | KT-0603R | KENTO | C2286 | LCSC
11 | 1 | XL-1608UBC-04 | D4 | LED0603-RD_BLUE |  | XL-1608UBC-04 | XINGLIGHT(成兴光) | C965807 | LCSC
12 | 2 | G6K-2F-Y DC3 | K1,K2 | RELAY-SMD_G6K-2F-Y |  | G6K-2F-Y DC3 | OMRON(欧姆龙) | C93168 | LCSC
13 | 1 | 3.9nH | L1 | L0402 | 3.9nH | LQG15HS3N9S02D | muRata(村田) | C77109 | LCSC
14 | 1 | BLM15AG601SN1D | L2 | L0402 |  | BLM15AG601SN1D | muRata(村田) | C76884 | LCSC
15 | 1 | 2.2uH | L3 | IND-SMD_L7.1-W6.5-P5.60 | 2.2uH | SPM6530T-2R2M | TDK | C76855 | LCSC
16 | 1 | ME6211C33M5G-N | LDO1 | SOT-23-5_L3.0-W1.7-P0.95-LS2.8-BL |  | ME6211C33M5G-N | MICRONE(南京微盟) | C82942 | LCSC
17 | 2 | DTC114EKAT146 | Q1,Q2 | SOT-346_L2.9-W1.6-P1.90-LS2.8-TR-CW |  | DTC114EKAT146 | ROHM(罗姆) | C79971 | LCSC
18 | 2 | 22Ω | R4,R5 | R0402 | 22Ω | RC0402JR-0722RL | YAGEO(国巨) | C93929 | LCSC
19 | 7 | 10kΩ | R6,R7,R8,R13,R14,R17,R20 | R0402 | 10kΩ | RC0402FR-0710KL | YAGEO(国巨) | C60490 | LCSC
20 | 2 | 5.1kΩ | R9,R10 | R0402 | 5.1kΩ | 0402WGF5101TCE | UNI-ROYAL(厚声) | C25905 | LCSC
21 | 1 | 100kΩ | R11 | R0402 | 100kΩ | 0402WGF1003TCE | UNI-ROYAL(厚声) | C25741 | LCSC
22 | 1 | 1kΩ | R12 | R0603 | 1kΩ | 0603WAJ0102T5E | UNI-ROYAL(厚声) | C25585 | LCSC
23 | 1 | NCP18XH103F03RB | R16 | R0603 |  | NCP18XH103F03RB | muRata(村田) | C13564 | LCSC
24 | 1 | 3kΩ | R18 | R0402 | 3kΩ | 0402WGF3001TCE | UNI-ROYAL(厚声) | C25784 | LCSC
25 | 2 | B3U-1000P | S1,S2 | KEY-SMD_B3U-1000PM |  | B3U-1000P | OMRON(欧姆龙) | C231329 | LCSC
26 | 1 | ESP32-C3FH4 | U1 | QFN-32_L5.0-W5.0-P0.50-BL-EP3.7 |  | ESP32-C3FH4 | ESPRESSIF(乐鑫) | C2858491 | LCSC
27 | 1 | LGS5500EP | U3 | ESOP-8_L4.9-W3.9-P1.27-LS6.0-TL-EP3.3 |  | LGS5500EP | Legend-Si(棱晶半导体) | C5280699 | LCSC
28 | 1 | B4B-XH-A(LF)(SN) | U4 | CONN-TH_B4B-XH-A-LF-SN |  | B4B-XH-A(LF)(SN) | JST | C144395 | LCSC
29 | 1 | TYPE-C 16PIN 2MD(073) | USB1 | USB-C-SMD_TYPE-C-6PIN-2MD-073 |  | TYPE-C 16PIN 2MD(073) | SHOU HAN(首韩) | C2765186 | LCSC
30 | 1 | 40MHz | X1 | CRYSTAL-SMD_4P-L2.0-W1.6-BL-2 | 40MHz | T201640MFBDE2X | YJX(雅晶鑫) | C20885029 | LCSC
31 | 1 | 32.768kHz | X2 | CRYSTAL-SMD_L3.2-W1.5-1 | 32.768kHz | XKXGI-SUA-32.768K | YXC(扬兴晶振) | C5213671 | LCSC

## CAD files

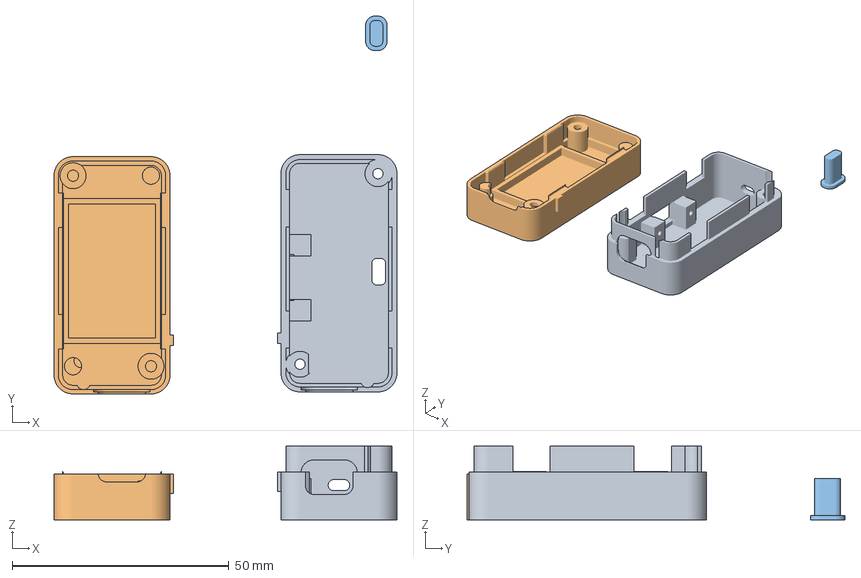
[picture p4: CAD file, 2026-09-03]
case/bambu-template.3mf
79.2 x 87.3 x 17.0 mm
openrz67-lid.stl
openrz67-base.stl
openrz67-lightpipe.stl

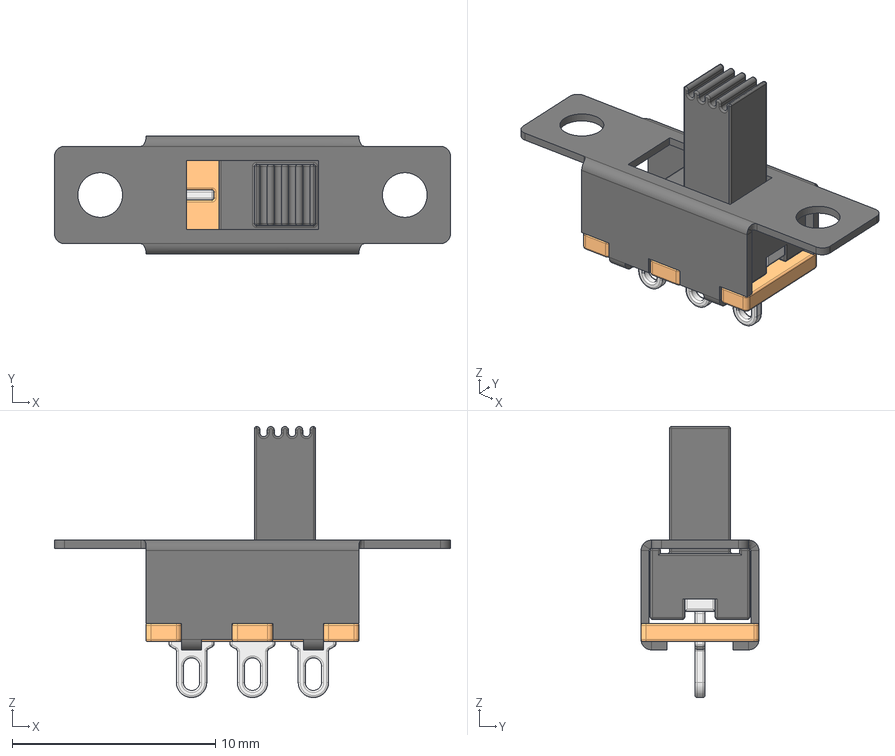
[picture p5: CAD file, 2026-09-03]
case/SS12F15.stp
19.5 x 5.80 x 13.3 mm
Metal part
Plastic part
Pin x 3
Handle

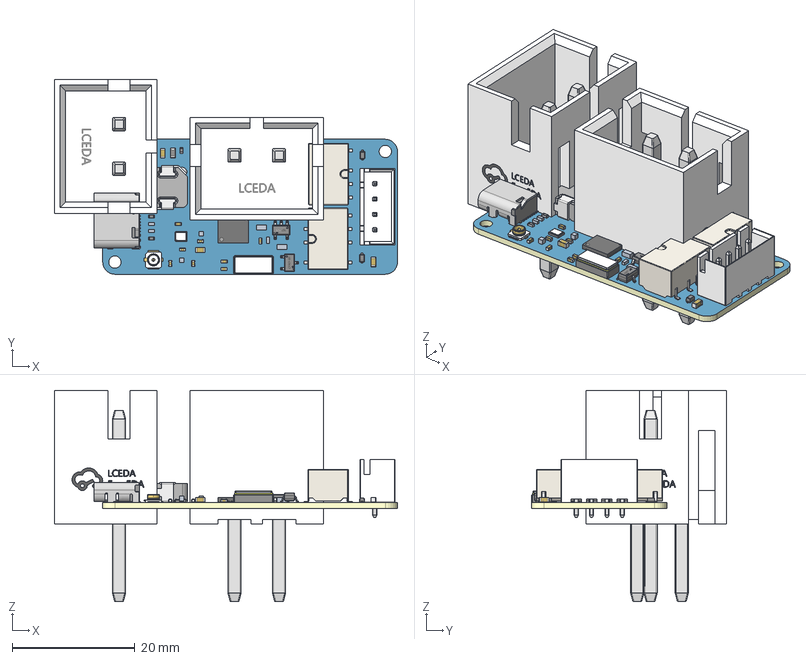
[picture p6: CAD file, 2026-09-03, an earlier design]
pcb/archive/2025-09-23-rev1/3D_ESP32CamTrigger_PCB_2_2025-09-23.step
55.8 x 31.7 x 34.4 mm
Board~MdMg
TopCopper~MdMg
BottomCopper~MdMg
TopFpcStiffener~MdMg
BottomFpcStiffener~MdMg
R8~R0402~R0402_L1.0-W0.5-H0.5~MdMg x 5
LED0603-RD~LED0603-RD~MdMg
USB-C-SMD_TYPE-C-6PIN-2MD-073~USB-C-SMD_TYPE-C-6PIN-2MD-073~MdMg
R0402~R0402_L1.0-W0.5-H0.4~MdMg x 8
R0603~R0603_L1.6-W0.8-H0.8~MdMg x 2
SOT-23-5_L3.0-W1.7-P0.95-LS2.8-BL~SOT-23-5_ L2.9-W1.6-H1.1-LS2.8-P0.95~MdMg
C0603~C0603_L1.6-W0.8-H0.8~MdMg x 9
SOD-523_L1.2-W0.8-LS1.6-RD~SOD-523_L1.2-W0.8-H0.7-LS1.6~MdMg x 2
L2~L0402~L0402_L1.0-W0.5-H0.5_BEAD~MdMg x 2
C0402~C0402_L1.0-W0.5-H0.5~MdMg x 11
CONN-TH_B2B-PH-K-S~CONN-TH_PH2.00-LI-2P~MdMg x 2
RF-SMD_FRF05002-JSS103M~RF-SMD_FRF05002-JSS103M~MdMg
C29~C0603~C0603_L1.6-W0.8-H0.8~MdMg x 3
CRYSTAL-SMD_L3.2-W1.5-1~CRYSTAL-SMD_L3.2-W1.5-1~MdMg
CONN-TH_B4B-XH-A-LF-SN~XH2.5-4A~MdMg
KEY-SMD_B3U-1000PM~KEY-SMD_B3U-1000P~MdMg x 2
RELAY-SMD_G6K-2F-Y~SMD-8_L10.0-W6.5-H5.4-LS7.8-P2.2~MdMg x 2
QFN-32_L5.0-W5.0-P0.50-BL-EP3.7~QFN-32_ L5.0-W5.0-H0.8-P0.50-BL-EP3.7~MdMg
ESOP-8_L4.9-W3.9-P1.27-LS6.0-TL-EP3.3~ESOP-8_ L4.9-W3.9-P1.27-LS6.0-TL-EP3.3~MdMg
IND-SMD_L7.1-W6.5-P5.60~IND-SMD_L7.1-W6.5-H3.0~MdMg
LED0603-RD_BLUE~LED0603-RD_BLUE~MdMg
CRYSTAL-SMD_4P-L2.0-W1.6-BL-2~CRYSTAL-SMD_4P-L2.0-W1.6-BL-2~MdMg
SOT-346_L2.9-W1.6-P1.90-LS2.8-TR-CW~SOT-346-3P_ L2.9-W1.7-H1.3-LS2.8-P0.95~MdMg x 2

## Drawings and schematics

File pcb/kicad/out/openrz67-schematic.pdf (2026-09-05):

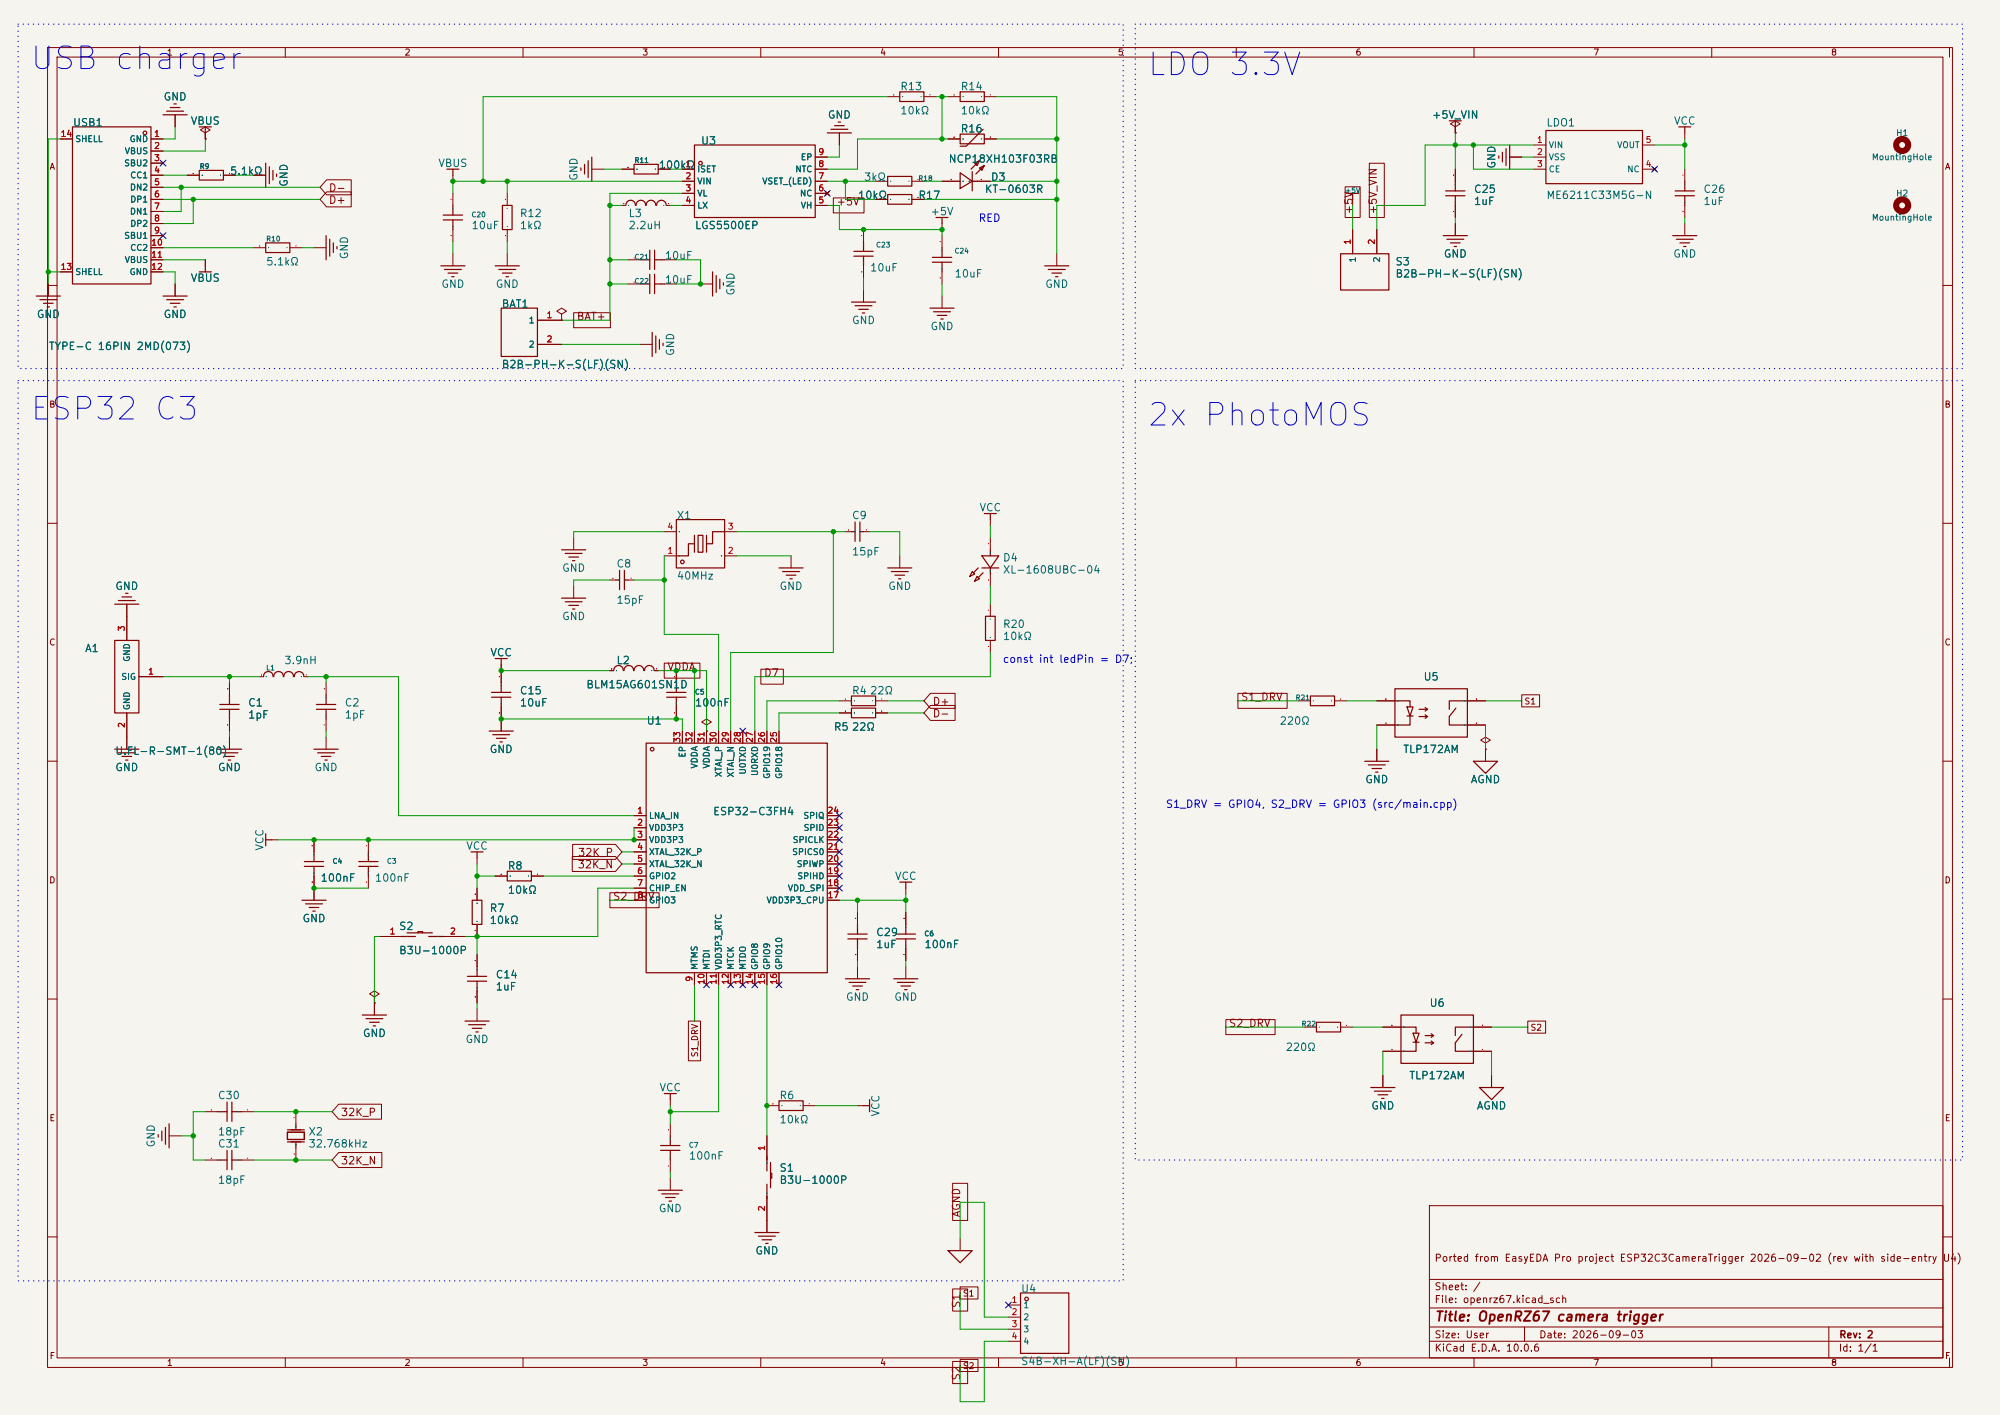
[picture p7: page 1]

VDD3P3_CPU 17 VDD_SPI 18 SPIHD 19 SPIWP 20 SPICS0 21 SPICLK 22 SPID 23 SPIQ 24 GPIO18 25 GPIO19 26 U0RXD 27 U0TXD 28 XTAL_N 29 XTAL_P 30 VDDA 31 VDDA 32 EP 33

Size: User | Rev: 2 | F Date: 2026-09-03
KiCad E.D.A. 10.0.6 | Id: 1/1

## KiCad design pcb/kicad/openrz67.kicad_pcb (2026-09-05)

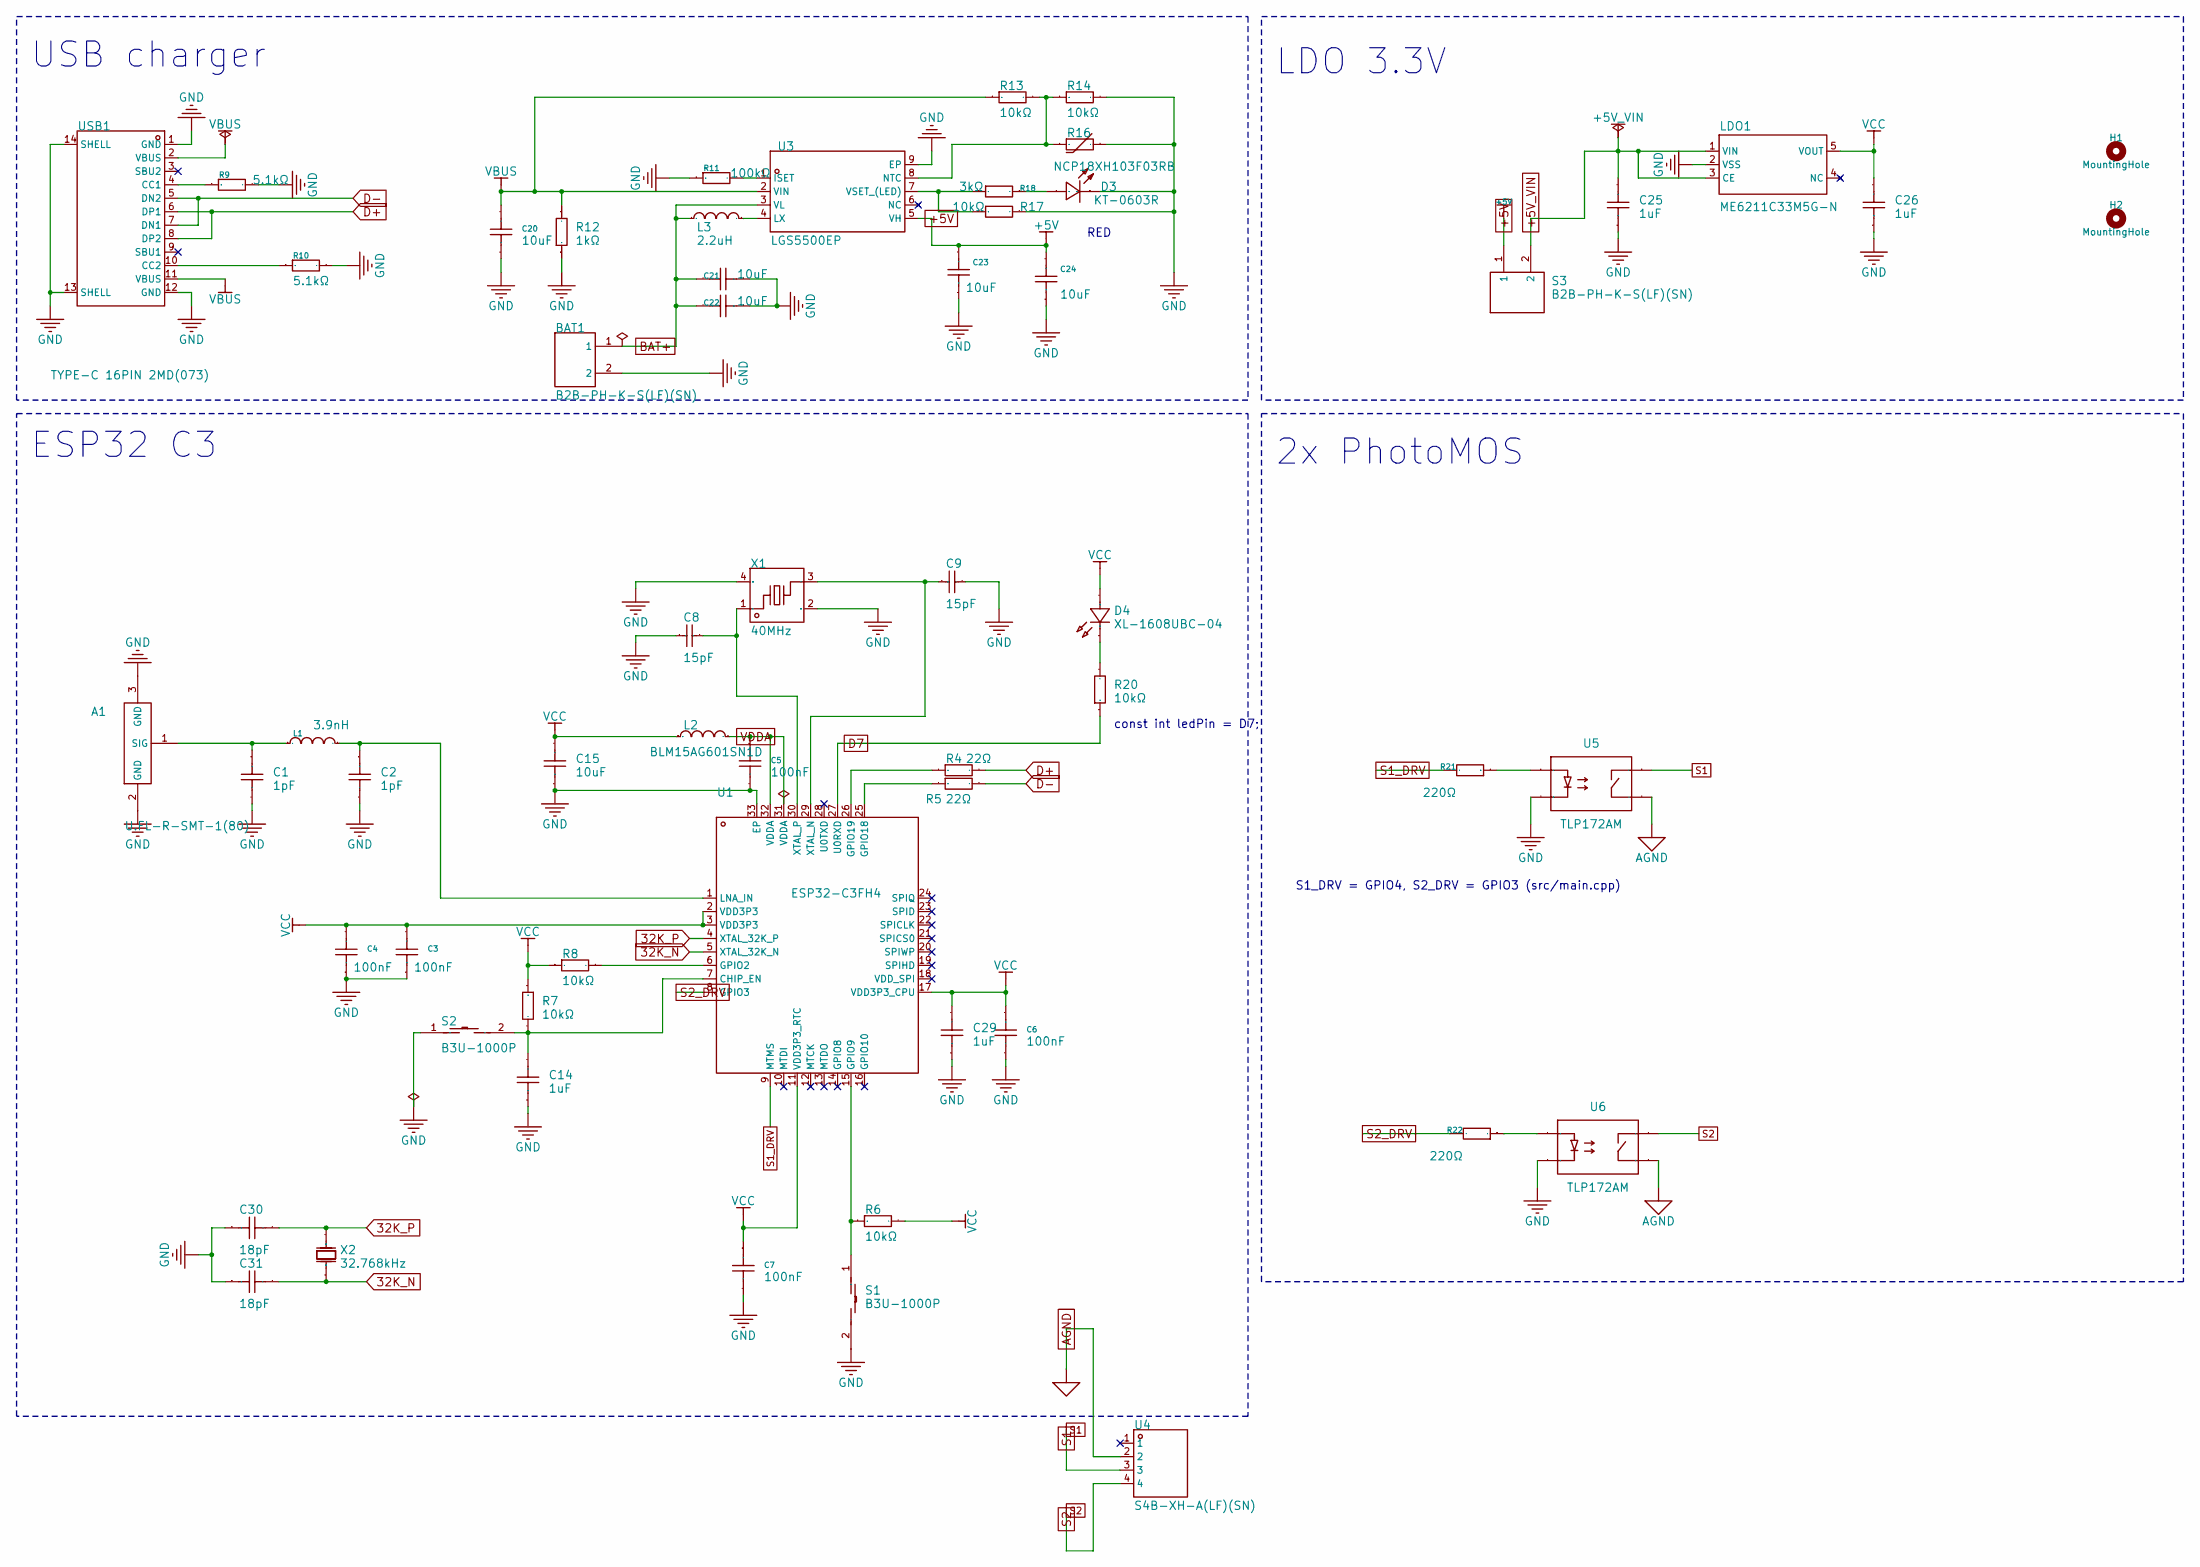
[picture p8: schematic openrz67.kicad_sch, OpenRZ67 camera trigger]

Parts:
A1: U.FL-R-SMT-1(80); RF-SMD_FRF05002-JSS103M; Manufacturer Part U.FL-R-SMT-1(80); LCSC Part Name IPEX 内针
BAT1: B2B-PH-K-S(LF)(SN); CONN-TH_B2B-PH-K-S; Manufacturer Part B2B-PH-K-S(LF)(SN); LCSC Part Name 1x2P 间距:2mm 直插 系列:PH
C1, C2: 1pF; C0402; Manufacturer Part CC0402CRNPO9BN1R0; LCSC Part Name 1pF 50V
C3, C4, C5, C6, C7: 100nF; C0402; Manufacturer Part GRM155R71H104KE14D; LCSC Part Name 100nF ±10% 50V
C8, C9: 15pF; C0402; Manufacturer Part GJM1555C1H150FB01D; LCSC Part Name 15pF ±1% 50V
C14, C25, C26, C29: 1uF; C0603; Manufacturer Part CGA0603X5R105K500JT; LCSC Part Name 1uF ±10% 50V
C15, C20, C21, C22, C23, C24: 10uF; C0603; Manufacturer Part CL10A106MA8NRNC; LCSC Part Name 10uF ±20% 25V
C30, C31: 18pF; C0402; Manufacturer Part GRM1555C1H180FA01D; LCSC Part Name 18pF ±1% 50V
D3: KT-0603R; LED0603-RD; Manufacturer Part KT-0603R; LCSC Part Name 0603 红灯 高亮
D4: XL-1608UBC-04; LED0603-RD_BLUE; Manufacturer Part XL-1608UBC-04; LCSC Part Name XL-1608UBC-04
H1, H2: MountingHole; MountingHole_2.0mm_Pad3.0
L1: 3.9nH; L0402; Manufacturer Part LQG15HS3N9S02D; LCSC Part Name 3.9nH
L2: BLM15AG601SN1D; L0402; Manufacturer Part BLM15AG601SN1D; LCSC Part Name 单路 0402磁珠 阻抗600Ω@100MHz
L3: 2.2uH; IND-SMD_L7.1-W6.5-P5.60; Manufacturer Part SPM6530T-2R2M; LCSC Part Name 2.2uH ±20% 8.4A
LDO1: ME6211C33M5G-N; SOT-23-5_L3.0-W1.7-P0.95-LS2.8-BL; Manufacturer Part ME6211C33M5G-N; LCSC Part Name 输入6V 输出3.3V 500mA
R4, R5: 22Ω; R0402; Manufacturer Part 0402WGF220JTCE; LCSC Part Name 22Ω ±1% 62.5mW 厚膜电阻
R6, R7, R8, R13, R14, R17, R20: 10kΩ; R0402; Manufacturer Part RC0402FR-0710KL; LCSC Part Name 厚膜电阻 10kΩ ±1% 62.5mW
R9, R10: 5.1kΩ; R0402; Manufacturer Part 0402WGF5101TCE; LCSC Part Name 5.1kΩ ±1% 62.5mW 厚膜电阻
R11: 100kΩ; R0402; Manufacturer Part 0402WGF1003TCE; LCSC Part Name 100kΩ ±1% 62.5mW 厚膜电阻
R12: 1kΩ; R0603; Manufacturer Part 0603WAJ0102T5E; LCSC Part Name 1kΩ ±5% 100mW 厚膜电阻
R16: NCP18XH103F03RB; R0603; Manufacturer Part NCP18XH103F03RB; LCSC Part Name NCP18XH103F03RB
R18: 3kΩ; R0402; Manufacturer Part 0402WGF3001TCE; LCSC Part Name 3kΩ ±1% 62.5mW 厚膜电阻
R21, R22: 220Ω; R0402; Manufacturer Part 0402WGF2200TCE; LCSC Part Name 220Ω ±1% 62.5mW 厚膜电阻
S1, S2: B3U-1000P; KEY-SMD_B3U-1000PM; Manufacturer Part B3U-1000P; LCSC Part Name 3*2.5*1.6mm 立贴 轻触开关
S3: B2B-PH-K-S(LF)(SN); CONN-TH_B2B-PH-K-S; Manufacturer Part B2B-PH-K-S(LF)(SN); LCSC Part Name 1x2P 间距:2mm 直插 系列:PH
U1: ESP32-C3FH4; QFN-32_L5.0-W5.0-P0.50-BL-EP3.7; Manufacturer Part ESP32-C3FH4; LCSC Part Name ESP32-C3FH4
U3: LGS5500EP; ESOP-8_L4.9-W3.9-P1.27-LS6.0-TL-EP3.3; Manufacturer Part LGS5500EP; LCSC Part Name 1A充电,0.3A同步升压放电,超低待机2uA+的TP5400,ETA9697
U4: S4B-XH-A(LF)(SN); CONN-TH_S4B-XH-A-LF-SN; Current Rating 3A; Voltage Rating 250V; Manufacturer Part S4B-XH-A(LF)(SN); LCSC Part Name 1x4P 间距:2.5mm 弯插 系列:XH
U5, U6: TLP172AM; SMD-4_L4.6-W3.7-P2.54-LS7.0-BR; Manufacturer Part TLP172AM(TPL,E; LCSC Part Name TLP172AM(TPL,E
USB1: TYPE-C 16PIN 2MD(073); USB-C-SMD_TYPE-C-6PIN-2MD-073; Manufacturer Part TYPE-C 16PIN 2MD(073); LCSC Part Name Type-C 母 卧贴
X1: 40MHz; CRYSTAL-SMD_4P-L2.0-W1.6-BL-2; Manufacturer Part T201640MFBDE2X; LCSC Part Name 40MHz ±10ppm 12pF
X2: 32.768kHz; CRYSTAL-SMD_L3.2-W1.5-1; Manufacturer Part XKXGI-SUA-32.768K; LCSC Part Name YST310S 32.768KHZ 2P 3215 12.5PF ±20PPM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

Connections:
32K_N: C31.2, U1.5 (XTAL_32K_N), X2.1 (OSC1)
32K_P: C30.2, U1.4 (XTAL_32K_P), X2.2 (OSC2)
+5V: C23.2, C24.2, S3.1, U3.5 (VH)
+5V_VIN: C25.2, LDO1.1 (VIN), LDO1.3 (CE), S3.2
AGND: U4.2, U5.3 (D), U6.3 (D)
BAT+: BAT1.1, C21.2, C22.2, L3.1, U3.3 (VL)
D7: R20.1, U1.27 (U0RXD)
D+: R4.2, USB1.6 (DP1), USB1.8 (DP2)
D-: R5.2, USB1.5 (DN2), USB1.7 (DN1)
GND: A1.2 (GND), A1.3 (GND), BAT1.2, C1.2, C2.2, C3.1, C4.1, C5.2, C6.2, C7.2, C8.1, C9.2, C14.1, C15.1, C20.1, C21.1, C22.1, C23.1, C24.1, C25.1, C26.1, C29.1, C30.1, C31.1, D3.1 (K), LDO1.2 (VSS), R9.2, R10.2, R11.1, R12.1, R14.2, R16.2, R17.2, S1.2, S2.1, U1.33 (EP), U3.9 (EP), U5.2 (K), U6.2 (K), USB1.1 (GND), USB1.12 (GND), USB1.13 (SHELL), USB1.14 (SHELL), X1.2 (GND), X1.4 (GND)
unnamed: A1.1 (SIG), C1.1, L1.1
unnamed: D3.2 (A), R18.2
unnamed: D4.1 (K), R20.2
unnamed: C14.2, R7.2, S2.2, U1.7 (CHIP_EN)
unnamed: R8.2, U1.6 (GPIO2)
unnamed: R6.1, S1.1, U1.15 (GPIO9)
unnamed: R5.1, U1.25 (GPIO18)
unnamed: R4.1, U1.26 (GPIO19)
unnamed: C2.1, L1.2, U1.1 (LNA_IN)
unnamed: C9.1, U1.29 (XTAL_N), X1.3
unnamed: C8.2, U1.30 (XTAL_P), X1.1
unnamed: R11.2, U3.1 (ISET)
unnamed: L3.2, U3.4 (LX)
unnamed: R13.2, R14.1, R16.1, U3.8 (NTC)
unnamed: R17.1, R18.1, U3.7 (VSET_(LED))
unnamed: R21.1, U5.1 (A)
unnamed: R22.1, U6.1 (A)
unnamed: R9.1, USB1.4 (CC1)
unnamed: R10.1, USB1.10 (CC2)
S1: U4.3, U5.4 (D)
S1_DRV: R21.2, U1.9 (MTMS)
S2: U4.4, U6.4 (D)
S2_DRV: R22.2, U1.8 (GPIO3)
VBUS: C20.2, R12.2, R13.1, U3.2 (VIN), USB1.2 (VBUS), USB1.11 (VBUS)
VCC: C3.2, C4.2, C6.1, C7.1, C15.2, C26.2, C29.2, D4.2 (A), L2.1, LDO1.5 (VOUT), R6.2, R7.1, R8.1, U1.2 (VDD3P3), U1.3 (VDD3P3), U1.11 (VDD3P3_RTC), U1.17 (VDD3P3_CPU)
VDDA: C5.1, L2.2, U1.31 (VDDA), U1.32 (VDDA)

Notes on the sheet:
RED
const int ledPin = D7;
USB charger
LDO 3.3V
2x PhotoMOS
ESP32 C3
S1_DRV = GPIO4, S2_DRV = GPIO3 (src/main.cpp)

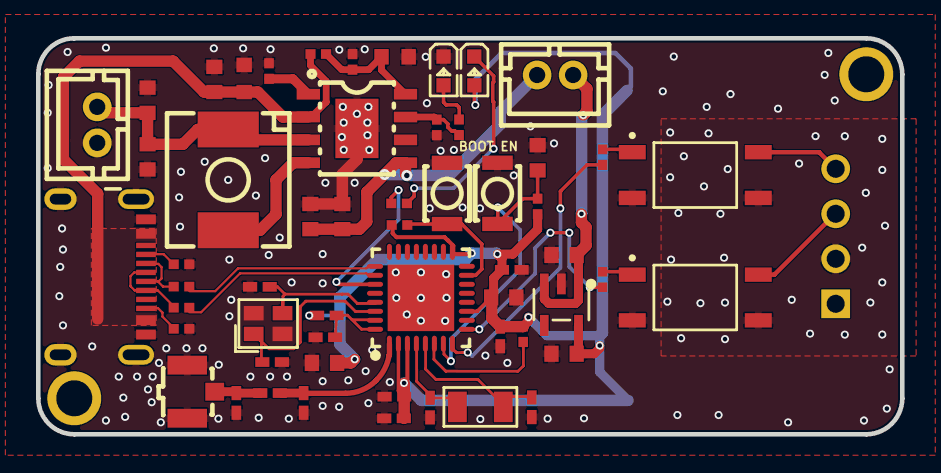
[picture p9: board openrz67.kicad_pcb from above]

Board: 2 copper layers, 48.0 x 22.0 mm, 59 parts (0 on the bottom side), 36 nets.

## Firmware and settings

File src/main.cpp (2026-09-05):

#include <Arduino.h>
#include <BLEDevice.h>
#include <BLEServer.h>
#include <esp_pm.h>

#define SERVICE_UUID        "c9239c9e-6fc9-4168-b3aa-53105eb990b0"
#define CHARACTERISTIC_UUID "458d4dc9-349f-401d-b092-a2b1c55f5319"

#define DELAY 2000
#define BLINK_SPEED 500
#define COUNTDOWN_DURATION 10000  // 10 seconds in milliseconds

// Suppress serial output for normal builds to save resources
// Set VERBOSE to 1 to enable serial output
#define VERBOSE 0
#if !VERBOSE
  struct NullStream {
      template<typename T> NullStream& operator<<(T const&) { return *this; }
      void print(...) {}
      void println(...) {}
      void setTxTimeoutMs(...) {}
      void begin(...) {}
  };
static NullStream nullSerial;
#define Serial nullSerial
#endif

constexpr int ledPin = 20; // GPIO20 (U0RXD)
constexpr int shutterPinS2 = 3; // GPIO3, drives U6 (camera S2)
constexpr int shutterPinS1 = 4; // GPIO4, drives U5 (camera S1); rev 1 used GPIO21 (U0TXD)

int incoming;
unsigned long now;
unsigned long timestampButton;
unsigned long countdownStartTime;
unsigned long countdownDuration = COUNTDOWN_DURATION; // Default to 10 seconds
bool countdownActive = false;
bool bulbModeActive = false;
unsigned long lastCountdownPrint = 0;

BLEServer *pServer = nullptr;
bool deviceConnected = false;
bool oldDeviceConnected = false;

void endBulbMode();
void startCountdown(unsigned long durationMs);
void cancelCountdown();

void openShutter() {
    Serial.println("Setting shutterPins HIGH...");
    digitalWrite(shutterPinS1, HIGH);
    delay(10); // Allow S1's PhotoMOS to turn on before requesting release.
    digitalWrite(shutterPinS2, HIGH);
}

void closeShutter() {
    Serial.println("Setting shutterPins LOW...");
    digitalWrite(shutterPinS2, LOW);
    digitalWrite(shutterPinS1, LOW);
}

void triggerShutter() {
    Serial.println("Trigger shutter");
    endBulbMode();
    openShutter();
    delay(100);
    closeShutter();
}

void startBulbMode() {
    Serial.println("Starting bulb mode - shutter opening");
    bulbModeActive = true;
    openShutter();
}

void endBulbMode() {
    Serial.println("Ending bulb mode - shutter closing");
    bulbModeActive = false;
    closeShutter();
}


void startCountdown(unsigned long durationMs) {
    endBulbMode();
    // Clear stale button-1 state so the trigger timeout in loop()
    // doesn't fight the countdown blink over the LED pin
    incoming = 0;
    countdownActive = false;
    countdownDuration = durationMs;
    countdownStartTime = millis();
    lastCountdownPrint = 0;
    countdownActive = true;
    digitalWrite(ledPin, HIGH);
    Serial.print("Starting ");
    Serial.print(durationMs / 1000);
    Serial.println("-second countdown...");
}

void cancelCountdown() {
    countdownActive = false;
    countdownStartTime = 0;
    digitalWrite(ledPin, LOW);
    Serial.println("Countdown cancelled");
}

class BleServerCallback : public BLEServerCallbacks {
    void onConnect(BLEServer *pServer) override {
        Serial.println("*** BLE CLIENT CONNECTED ***");
        deviceConnected = true;
    };

    void onDisconnect(BLEServer *pServer) override {
        Serial.println("*** BLE CLIENT DISCONNECTED ***");
        deviceConnected = false;

        // Immediately restart advertising for new connections
        delay(100); // Minimal delay for cleanup
        pServer->startAdvertising();
        Serial.println("*** RESTARTED ADVERTISING ***");
    };

};

class BLECharacteristicCallback : public BLECharacteristicCallbacks {
    void onWrite(BLECharacteristic *pCharacteristic) override {
        now = millis();
        std::string data = pCharacteristic->getValue();
        
        if (data.length() == 1) {
            // Legacy single-byte protocol
            incoming = data[0];
            Serial.print("BLE command received (legacy): ");
            Serial.println(incoming);

            int button = incoming / 10;
            int value = incoming % 10;

            switch (button) {
                case 1:
                    Serial.print("Button 1, value = ");
                    Serial.println(value);
                    if (value == 1) {
                        // Button 1 PRESS - trigger shutter
                        // A pending countdown would keep blinking the LED and
                        // fire the shutter a second time, so cancel it first
                        cancelCountdown();
                        digitalWrite(ledPin, HIGH);
                        timestampButton = now;
                        triggerShutter();
                    } else {
                        // Button 1 RELEASE - just turn off LED, don't trigger again
                        digitalWrite(ledPin, LOW);
                    }
                    break;
                case 2:
                    Serial.print("Button 2 (Bulb Mode), value = ");
                    Serial.println(value);
                    if (value == 1) {
                        // Start bulb mode
                        // A pending countdown would end the bulb exposure when
                        // it expires, so cancel it first
                        cancelCountdown();
                        digitalWrite(ledPin, HIGH);
                        startBulbMode();
                    } else {
                        // End bulb mode
                        digitalWrite(ledPin, LOW);
                        endBulbMode();
                    }
                    break;
                case 3:
                    Serial.print("Button 3 (Legacy Countdown), value = ");
                    Serial.println(value);
                    if (value == 1) {
                        // Start countdown with default duration
                        startCountdown(COUNTDOWN_DURATION);
                    } else {
                        // Cancel countdown
                        cancelCountdown();
                    }
                    break;
                default:
                    Serial.println("Unknown button triggered");
            }
        } else if (data.length() == 3) {
            // New multi-byte protocol
            uint8_t command = data[0];
            uint8_t duration = data[1];
            uint8_t action = data[2];
            
            Serial.print("BLE command received (multi-byte): [");
            Serial.print(command);
            Serial.print(", ");
            Serial.print(duration);
            Serial.print(", ");
            Serial.print(action);
            Serial.println("]");
            
            if (command == 3) { // Countdown command
                if (action == 1) {
                    // Start countdown with specified duration
                    startCountdown(duration * 1000UL); // Convert seconds to milliseconds
                } else {
                    // Cancel countdown
                    cancelCountdown();
                }
            } else {
                Serial.println("Unknown multi-byte command");
            }
        } else {
            Serial.print("Invalid command length: ");
            Serial.println(data.length());
        }
    }
};

void setupBLE() {
    Serial.println("Initializing BLE...");

    BLEDevice::init("OpenRZ67");
    pServer = BLEDevice::createServer();
    pServer->setCallbacks(new BleServerCallback());

    BLEService *pService = pServer->createService(SERVICE_UUID);

    BLECharacteristic *pCharacteristic = pService->createCharacteristic(
            CHARACTERISTIC_UUID,
            BLECharacteristic::PROPERTY_READ |
            BLECharacteristic::PROPERTY_WRITE_NR
    );
    pCharacteristic->setCallbacks(new BLECharacteristicCallback());
    pCharacteristic->setValue("Hello from OpenRZ67!");

    pService->start();
    Serial.println("BLE service and characteristic configured");

    BLEAdvertising *pAdvertising = BLEDevice::getAdvertising();
    pAdvertising->addServiceUUID(SERVICE_UUID);
    pAdvertising->setScanResponse(true);
    pAdvertising->setMinPreferred(0);
    pAdvertising->setMaxPreferred(0);

    // Additional advertising configuration for better discoverability
    BLEAdvertisementData adData;
    adData.setName("OpenRZ67");
    adData.setCompleteServices(BLEUUID(SERVICE_UUID));
    pAdvertising->setAdvertisementData(adData);

    BLEAdvertisementData scanResponseData;
    scanResponseData.setName("OpenRZ67");
    scanResponseData.setCompleteServices(BLEUUID(SERVICE_UUID));
    pAdvertising->setScanResponseData(scanResponseData);

    Serial.println("BLE advertising configured");

    // Set advertising power (most important for battery life)
    esp_err_t adv_power = esp_ble_tx_power_set(ESP_BLE_PWR_TYPE_ADV, ESP_PWR_LVL_N0);  // 0dBm
    Serial.print("Set advertising power to 0dBm: ");
    Serial.println(adv_power == ESP_OK ? "SUCCESS" : "FAILED");

    // Set default power for other operations
    esp_err_t default_power = esp_ble_tx_power_set(ESP_BLE_PWR_TYPE_DEFAULT, ESP_PWR_LVL_N0);  // 0dBm
    Serial.print("Set default power to 0dBm: ");
    Serial.println(default_power == ESP_OK ? "SUCCESS" : "FAILED");

    // Start advertising
    pAdvertising->start();
    Serial.println("*** BLE ADVERTISING STARTED - Device visible as 'OpenRZ67' ***");
}

void checkToReconnect() //added
{
    if (deviceConnected && !oldDeviceConnected) {
        Serial.println("Reconnected");
        oldDeviceConnected = deviceConnected;
    }
    if (!deviceConnected && oldDeviceConnected) {
        Serial.println("Connection state updated: disconnected");
        oldDeviceConnected = deviceConnected;
    }
}

void configurePowerManagement() {
    esp_pm_config_esp32c3_t pm_config = {
        .max_freq_mhz = 80,
        .min_freq_mhz = 10,
        .light_sleep_enable = true
    };
    esp_pm_configure(&pm_config);

    Serial.println("Power management configured for frequency scaling");
}

void setup() {

#if ARDUINO_USB_CDC_ON_BOOT
    Serial.setTxTimeoutMs(0); // Don't block when no serial monitor connected
#endif
    Serial.begin(115200);
    delay(500);  // Brief delay for serial stability

    setupBLE();

    Serial.println("=== OPENRZ67 TRIGGER STARTING ===");
    Serial.print("ESP32 Chip Model: ");
    Serial.println(ESP.getChipModel());
    Serial.print("ESP32 Chip Revision: ");
    Serial.println(ESP.getChipRevision());
    Serial.print("Flash Size: ");
    Serial.print(ESP.getFlashChipSize() / (1024 * 1024));
    Serial.println(" MB");
    Serial.print("Free Heap: ");
    Serial.print(ESP.getFreeHeap());
    Serial.println(" bytes");

    Serial.println("Configuring GPIO pins...");
    pinMode(ledPin, OUTPUT);
    pinMode(shutterPinS1, OUTPUT);
    pinMode(shutterPinS2, OUTPUT);
    Serial.print("LED pin configured: GPIO");
    Serial.println(ledPin);
    Serial.print("Shutter pin configured: GPIO");
    Serial.println(shutterPinS2);
    Serial.print("Shutter pin configured: GPIO");
    Serial.println(shutterPinS1);

    // Configure power management for frequency scaling
    configurePowerManagement();

    Serial.println("=== SETUP COMPLETE - SYSTEM READY ===");
    Serial.println("Hello from Open RZ67 Trigger!");
}


void loop() {

    checkToReconnect();

    if (deviceConnected) {
        now = millis(); // Store current time

        if (incoming == 11 and digitalRead(ledPin) and now > timestampButton + DELAY) {
            // Shutter has fired, disable LED
            digitalWrite(ledPin, LOW);
            Serial.println("Button 1 timeout reached");
        }
    }

    // Handle Arduino countdown - runs regardless of connection status
    if (countdownActive && countdownStartTime > 0) {
        unsigned long currentTime = millis();
        unsigned long elapsed = currentTime - countdownStartTime;

        // Print countdown status only once per second to avoid spam
        if (currentTime - lastCountdownPrint >= 1000) {
            unsigned long secondsRemaining = (countdownDuration - elapsed) / 1000;
            Serial.print("Countdown: ");
            Serial.print(secondsRemaining);
            Serial.println(" seconds remaining");
            lastCountdownPrint = currentTime;
        }

        if (elapsed >= countdownDuration) {
            // Countdown complete - trigger shutter
            countdownActive = false;
            countdownStartTime = 0;
            triggerShutter();
            digitalWrite(ledPin, LOW);
            Serial.println("Countdown complete - shutter triggered!");
        } else {
            // Blink LED during countdown (faster blink than button 2)
            if (elapsed % 250 < 125) {  // 250ms cycle, on for first 125ms
                digitalWrite(ledPin, HIGH);
            } else {
                digitalWrite(ledPin, LOW);
            }
        }
    }

    // Handle bulb mode LED indication - steady light when active
    if (bulbModeActive) {
        digitalWrite(ledPin, HIGH);
    }

    delay(10);

}

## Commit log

2025-08-18 move countdown logic to esp32
2025-09-09 Wip custom esp32-c3 board
2025-09-23 Add PCB fabrication files
    [BOM_ESP32CamTrigger_1_ESP32CamTrigger_PCB_2_2025-09-23.csv, PickAndPlace_ESP32CamTrigger_PCB_2_2025-09-23.csv]
2025-09-27 Add CPU scaling and fix issues with BLE power settings
    [main.cpp]
2025-09-28 Cleanup serial prints
2026-07-15 Cancel pending countdown when trigger or bulb mode is activated
    A countdown left running from a previous mode kept blinking the LED and
    fired the shutter a second time when it expired (ending bulb exposures
    early). Trigger and bulb activation now cancel any active countdown, and
    starting a countdown clears stale button-1 state so the trigger timeout
    no longer competes with the countdown blink for the LED pin.
    [main.cpp]
2026-08-02 Replace Fritzing diagram with generic wiring schematic
2026-08-02 Clarify 3 V relay reference circuit
2026-08-08 Clarify relay wiring diagram
2026-09-03 New case (#2)
    [SS12F15.stp, bambu-template.3mf]
2026-09-03 Port PCB from EasyEDA Pro to KiCad 10
    Source now lives in pcb/kicad (openrz67.*) with project-local symbol and
    footprint libraries, tools/post_import.py for design rules/zone settings,
    and generated outputs in out/. EasyEDA Pro v2/v3 exports are archived in pcb/.
    - U4 is the side-entry S4B-XH-A (LCSC C157925); SW3 removed
    - Jeefun A3 sheet-frame template replaced by a KiCad title block
    - power flags annotated, local labels made global, nets renamed to KiCad names
    - DRC/ERC/schematic parity clean; Gerbers compared against the 2025-09-23 set
    [openrz67-B_Cu.gbl, openrz67-B_Mask.gbs, openrz67-B_Paste.gbp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]
2026-09-03 KiCad: archive rev-1 files, add 3D models, 0.3 mm edge clearance, cleanup
    - move 2025-09-23 fabrication files and EasyEDA exports to pcb/archive/
    - fetch LCSC 3D models with easyeda2kicad (tools/fetch_3d.sh); .wrl committed,
    .step gitignored; footprints repointed from dangling EASYEDA_MODELS paths
    - copper-to-edge 0.30 mm with a .kicad_dru exemption for the USB-C pads
    - remove two dangling vias and a 0.1 mm track stub; move two USB1 polygons
    the importer put on Edge.Cuts to F.Fab
    - bottom silkscreen: OpenRZ67 Trigger v2 / 2026-09
    - regenerate out/ (gerber zip, pos, BOM, PDF, renders, DRC report)
    [3D_ESP32CamTrigger_PCB_2_2025-09-23.step, BOM_ESP32CamTrigger_1_ESP32CamTrigger_PCB_2_2025-09-23.csv, PickAndPlace_ESP32CamTrigger_PCB_2_2025-09-23.csv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]
2026-09-03 KiCad: proper ERC pin types, mounting-hole symbols, courtyards, silk cleanup
    - pin electrical types for ESP32-C3, LGS5500, ME6211 and USB-C; passives passive;
    PWR_FLAGs on GND/AGND/BAT+/VBUS/+5V_VIN/VDDA; ERC severities back to default
    (0 errors, 8 harmless dangling-wire warnings)
    - symbol library pruned to the parts in use, embedded copies regenerated
    - H1/H2: MountingHole symbols + MountingHole_2.0mm_Pad3.0 footprint, linked
    - courtyards rebuilt from pads/body (+0.05 mm); 0402/0603 and overhanging
    connector silk moved to F.Fab; BOOT/EN label moved above the buttons
    - tools/fetch_3d.sh bootstraps easyeda2kicad via uvx/pipx/venv; tools/export_step.sh
    - DRC 0 errors / 0 unconnected / pa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
    [openrz67-B_Cu.gbl, openrz67-B_Mask.gbs, openrz67-B_Paste.gbp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]
2026-09-03 Rev 2: battery connector on the bottom side, facing inward
    BAT1 changes from the vertical THT B2B-PH-K-S to the SMD side-entry
    S2B-PH-SM4-TB (LCSC C295747) on B.Cu at the left end, opening toward the
    board centre, so the cell lies flat under the PCB and plugs in without a
    lead bend. BAT+ is brought down with a 0.6/0.3 via next to C22; GND uses the
    bottom pour. Five GND stitching vias under the new pads removed; bottom
    silkscreen labels relocated. Symbol, footprint and 3D model added to the
    project libraries. DRC 0 errors, parity clean; ERC unchanged.
    [openrz67-B_Cu.gbl, openrz67-B_Mask.gbs, openrz67-B_Paste.gbp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]
2026-09-03 Rev 2: widen board to 25 mm, add unpopulated 3-pin expansion header (GPIO4, 3V3, GND)
    - new 3 mm strip along the back edge; outline rebuilt as a clean rounded rectangle
    - J1 PinHeader 1x03 THT in the strip, excluded from BOM/POS; schematic Conn_01x03
    with global labels; GPIO4 = ESP32-C3 pad 9 (MTMS)
    - GPIO4 routed F.Cu stub -> via -> B.Cu around the VCC track west end -> strip;
    3V3 stub to the bottom VCC track; a few GND/AGND stitching vias removed, two
    added to tie isolated top-pour islands down
    - BAT1 nudged 0.15 mm off the front edge (0.3 mm copper-edge rule)
    - S3 kept THT: neither SMD PH variant fits without moving C14/C28/D4
    - DRC 0 errors / 0 unconnected / parity clean; ERC uncha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
    [openrz67-B_Cu.gbl, openrz67-B_Mask.gbs, openrz67-B_Paste.gbp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]
2026-09-03 J1: label GPIO4 / 3V3 / GND in silkscreen on both sides, header outline to F.Fab
    [openrz67-B_Cu.gbl, openrz67-B_Mask.gbs, openrz67-B_Paste.gbp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]
2026-09-03 Tooling: one regeneration script, fix the zone-fill rule ordering
    - tools/regen.sh rebuilds all of out/ in one run: rules and zone fill,
    Gerbers, drill + maps, zip, position file, BOM, schematic PDF, both
    renders, then DRC with parity and ERC. The old README recipe omitted
    ERC, the renders and the zip, which is how out/erc.rpt and the schematic
    PDF drifted behind the sources.
    - post_import.py filled zones with the DRC rules compiled at load time, not
    the ones it had just assigned, so the first run after a rule change filled
    with the previous clearances and only a second run converged. It now saves
    the rules, reloads, then fills. Verified: after altering min_clearance and
    min_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
2026-09-03 Revert the 25 mm widening and the J1 expansion header
    The header cost more than it bought. Reaching the new edge strip forced the
    GPIO4 return path across the bottom pour, which split the B.Cu ground under
    U1 and LDO1 off into a separate island and displaced three stitching vias
    next to the antenna trace. One GPIO, on a header that was not going to be
    populated, does not pay for that.
    There is no cheap way back either: a through-hole pad needs both layers clear
    at the same spot, and on this outline only two isolated positions qualify.
    Bottom-side solder pads do fit, but the cell now occupies the bottom. It
    belongs in the same pass as the enclosure rework, not before it.
    - Board back to 48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
    [openrz67-B_Cu.gbl, openrz67-B_Mask.gbs, openrz67-B_Paste.gbp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]
2026-09-03 Docs: make the three READMEs describe the board that is actually in the repo
    - Root README: U4 is S4B-XH-A, not B4B-XH-A; the battery connector is listed;
    rev 2 is marked as not yet fabricated, and connector part numbers now point
    at pcb/kicad/README.md instead of being restated a second time.
    - case/README.md: a banner saying the enclosure fits the fabricated 2025-09-23
    board only, because rev 2 moves BAT1 to the underside and the cell under the
    board. Its source-file references now point at pcb/archive/2025-09-23-rev1/,
    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
2026-09-03 Rev 2: decouple the ESP32-C3 analog supply behind the ferrite bead
    L2 sits between VCC and U1 pins 31/32 (VDDA, radio and ADC supply), but every
    3.3 V capacitor on the board was on the VCC side of it. A bead with no
    capacitor behind it is just series impedance: the radio's transmit bursts have
    to pull through it, and the noise it is meant to block has no path to ground.
    Espressif's reference design puts 0.1 uF at those pins.
    Rather than squeeze a new part into the 2 mm gap in front of the pins, reuse
    C5, the 100 nF that already sat 1.2 mm from L2 pin 2: move it to the far side
    of the bead. The net is now named VDDA.
    - Schematic: C5 moved onto the L2 -> U1 wire, global label VDDA on that ne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
    [openrz67-B_Cu.gbl, openrz67-B_Mask.gbs, openrz67-B_Paste.gbp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]
2026-09-04 Rev 2: replace the G6K relays with TLP172GM PhotoMOS, fix the JLCPCB CPL format
    Each shutter channel is now one Toshiba TLP172GM (LCSC C261926) with its LED
    driven from the GPIO through 330 R (C25104). K1/K2, the DTC114E drivers, the
    flyback diodes and the coil decoupling caps are gone: eight parts become four,
    the tallest top-side part drops from 5.2 to 2.2 mm, and no coil current is
    drawn while an exposure is held. Camera ground stays isolated: AGND touches
    only U4 pin 2 and the two PhotoMOS outputs, and the AGND pours were pulled in
    so the LED side sits in the GND domain.
    R4/R5 (USB 22 R) move to UNI-ROYAL 0402WGF220JTCE (C25092, Basic); JLCPCB
    had two of the Yageo part in stock.
    regen.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
    [openrz67-B_Cu.gbl, openrz67-B_Mask.gbs, openrz67-B_Paste.gbp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]
2026-09-04 Review follow-ups: S1 driver to GPIO4, 220 R LED resistors, S1_DRV/S2_DRV nets
    GPIO21 is U0TXD and idles high from the ROM boot log until setup() runs, so
    the S1 output was closed during every boot. Harmless on its own, since the
    camera needs S1 and S2 together, but GPIO4 (U1 pin 9, free) is a plain input
    at reset, and the move frees UART0 TX for logging. Firmware constants
    renamed to shutterPinS1 = 4 / shutterPinS2 = 3; builds.
    330 R gave 3.8 mA at worst-case VOH/VF, under Toshiba's 5 mA minimum; 220 R
    (C25091, Basic) gives 5.6 mA worst case, 9 mA typical.
    Nets D6/D1 (Wemos names) renamed S1_DRV/S2_DRV. The S2_DRV bottom-layer
    diagonal moved 0.3 mm to make room for the new via next to U1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
    [openrz67-B_Cu.gbl, openrz67-B_Mask.gbs, openrz67-B_Paste.gbp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]
2026-09-04 Update rev 2 PCB layout
    [openrz67-B_Cu.gbl, openrz67-B_Mask.gbs, openrz67-B_Paste.gbp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]
2026-09-04 Revert "Update rev 2 PCB layout"
    This reverts commit d763081e84975234f8d2c617ac684d1041c5a9e0.
    [openrz67-B_Cu.gbl, openrz67-B_Mask.gbs, openrz67-B_Paste.gbp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]
2026-09-05 Fix shutter activation sequence
    [main.cpp]
2026-09-05 Use lower-resistance PhotoMOS relays
    [openrz67-B_Cu.gbl, openrz67-B_Mask.gbs, openrz67-B_Paste.gbp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]
2026-09-05 Move battery connector back to top
    [openrz67-B_Cu.gbl, openrz67-B_Mask.gbs, openrz67-B_Paste.gbp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]
2026-09-05 Case: fit the rev 2 board, battery still beside the PCB
    Rev 2 keeps BAT1 on top in the rev 1 spot, so the battery-beside layout
    carries over. U4 is the only change that reaches the case: the side-entry
    S4B-XH-A's mouth is 9.2 mm from its pin row (F.Fab + .wrl agree), i.e.
    5.5 mm past the board edge, not the 2.4 mm the case-rev2 branch assumed.
    - pcb_overhang_right derived from the U4 reach (3.0 mm, mouth 0.3 inside
    the outer face); box 55.6 -> 58.6 wide
    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
2026-09-05 Update PhotoMOS wiring diagram
2026-09-05 Translate PCB research notes
2026-10-11 nrf case: sliding floor with latch
2026-10-11 nrf case: view.sh for CAD Viewer
2026-10-11 nrf case: view.sh runs its own viewer
2026-10-11 nrf case: lean latch slot so the floor is closed from below
2026-10-15 nrf: wiring diagram for perfboard variant
2026-10-15 Split into esp32/ and nrf/
2026-10-16 Fix camera pin order in perfboard wiring diagram
2026-10-18 nrf: readable schematic layout
2026-10-18 esp32: readable schematic layout
2026-10-20 Clarify RF board flashing setup
2026-10-29 nrf: stop GRTC before System OFF so the button wakes the board
2026-10-29 nrf: camera connector in camera pin order (rev B)
2026-10-29 nrf: rev A tested on the camera
2026-10-29 nrf: clear button latch before System OFF
2026-10-30 Remove ESP32 board, kept at tag esp32-final
2026-11-04 nrf: solder dome on the cell pad, no copper around it
2026-11-08 Mark nRF rev B as work in progress, point to tested ESP32 rev 2
2026-11-11 Build guide: any filament, tape Dupont ends together
2026-11-11 Make case render more realistic
2026-11-13 Drop ESP32 references from firmware comments
2026-11-13 Fix stale rev A and nRF52 labels, LED wording, ERC note
2026-11-13 Track the case STLs so nobody has to export them
2026-11-13 Add locating ribs so the board does not move in the case
2026-11-13 Fix case, build guide and camera port details from review
